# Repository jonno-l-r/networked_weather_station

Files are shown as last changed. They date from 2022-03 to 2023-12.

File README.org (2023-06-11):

#+title: Networked Weather Monitoring Station
#+options: h:4 num:nil toc:t

This is a full stack implementation of a networked weather monitoring station. The repository contains hardware designs, including printed circuit board (PCB) designs for the control and sensor breakout modules, mechanical assembly designs for the custom sensors, embedded sources for the microcontroller, and finally sources for a web API and GUI.

* Overview
#+HEADER: :imagemagick yes :iminoptions -density 400
#+HEADER: :fit yes :noweb yes
#+begin_src latex :file (cond-exp "doc/media/system_diagram0") :results file raw :exports results
  \import{doc/media}{system_diagram.pdf_tex}
#+end_src

#+CAPTION: High level system diagram
#+LABEL: fig:doc/media/system_diagram0
#+RESULTS:
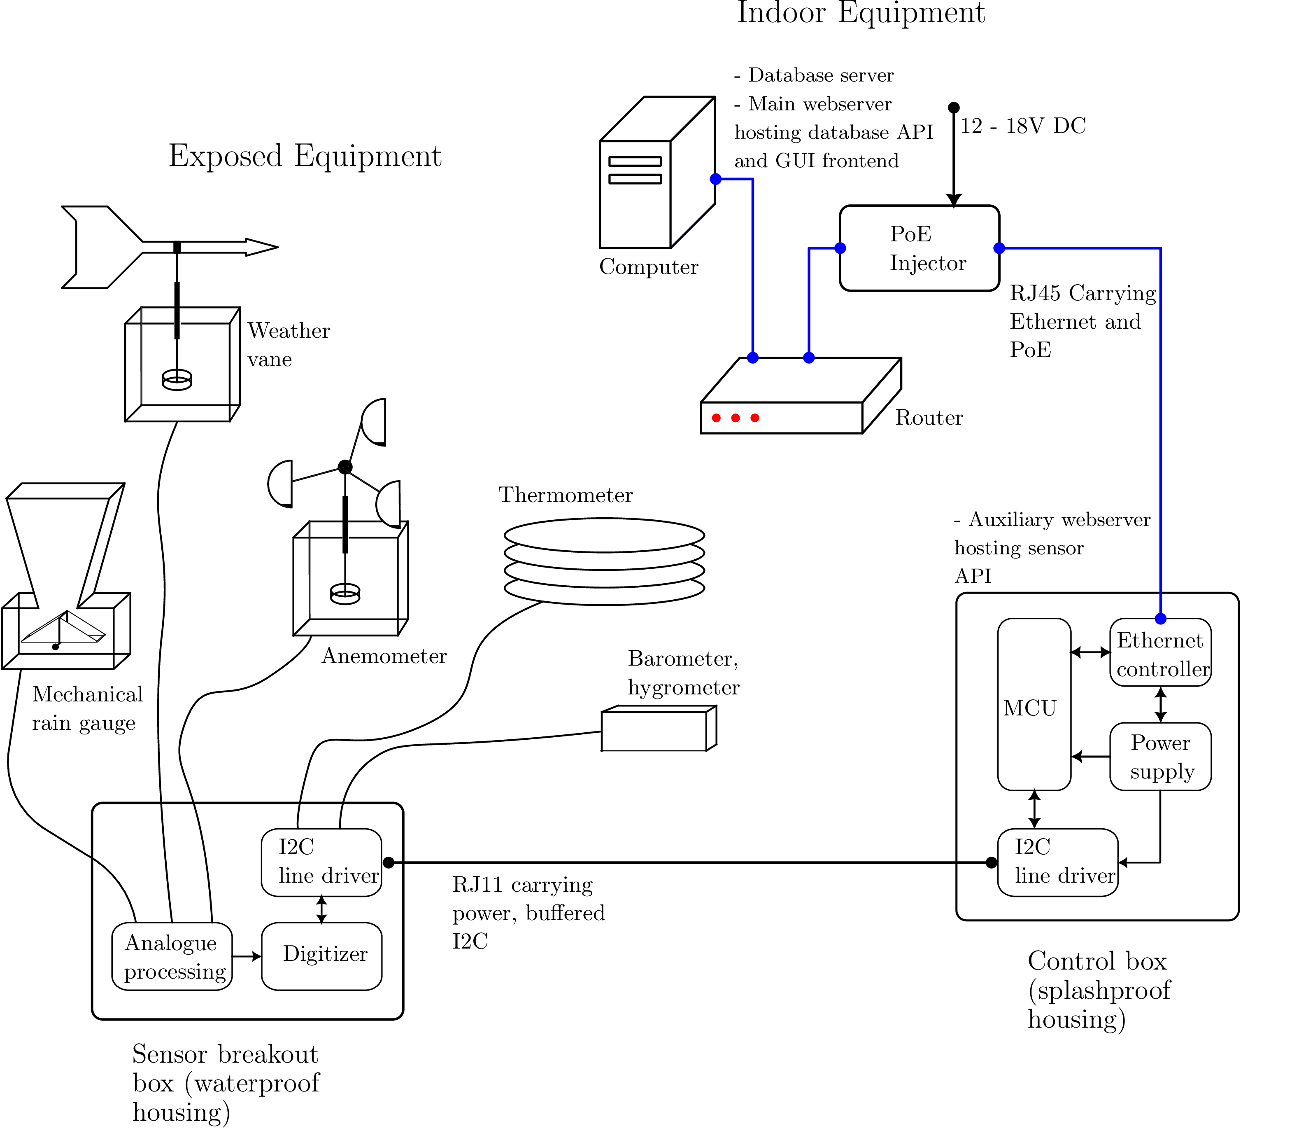
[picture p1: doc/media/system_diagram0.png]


The system is comprised of three main elements; the sensor breakout module and associated sensors, the control module, and the host PC.

All sensors are connected to the breakout module (which is intended to be in close proximity to the sensor cluster). The breakout module is connected to the controller via a single RJ11 link. The controller should be housed in a relatively protected environment. The controller connects to a network switch or router via a power over ethernet injector.

The PC queries the controller over the network at regular intervals, processing the data from the sensors to extrapolate measurements and recording the results into a database. The PC also hosts a web API for the database, along with a web GUI to plot measurement history and current observations.

* Repository Structure
The repository is organised into the following directories;
#+begin_src plantuml :file doc/media/repo.png :exports results
  @startuml
  salt
  {
          {T
          + root
          ++ cad
          +++ electrical
          +++ mechanical
          ++ release
          +++ electrical
          +++ mechanical
          ++ src
          +++ atmega328
          +++ server
          }
  }
  @enduml
#+end_src

#+RESULTS:


Where =cad= holds the electrical and mechanical CAD project files and libraries, =release= holds the exported designs (gerber files, bill of materials and schematics), and =src= holds all microcontroller and server source files and configuration.

The =cad= part of the repository is organised as shown;
#+begin_src plantuml :file doc/media/repo_cad.png :exports results
  @startuml
  salt
  {
          {T
          + root
          ++ cad
          +++ electrical
          ++++ <PCB-module-name>
          +++++ <PCB-module-name>.pro
          +++++ <PCB-module-name>.kicad_pcb
          +++++ <PCB-module-name>.sch
          +++ mechanical
          +++ library
          ++++ custom
          +++++ kicad
          ++++++ footprint
          ++++++ symbol
  }
  }
  @enduml
#+end_src

#+RESULTS:
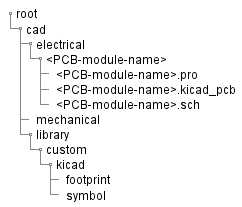
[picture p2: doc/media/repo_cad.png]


The =release= part of the repository is organised as shown below;
#+begin_src plantuml :file doc/media/repo_release.png :exports results
  @startuml
  salt
  {
          {T
          + release
          ++ electrical
          +++ <PCB-module-name>
          ++++ gerber
          ++++ bom.csv
          ++++ schematic.csv
          ++ mechanical
          +++ <mechanical-assembly-name>
          ++++ slicer
          ++++ renders
          ++++ bom.csv
          }
  }
  @enduml
#+end_src

#+RESULTS:
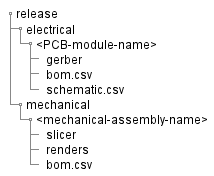
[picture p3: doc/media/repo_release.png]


=release= holds the outputs of the CAD projects in the =cad= directory. The release files are generated on each tagged commit, so the outputs in =release= on any given commit were generated from the projects in =cad= on the last /tagged/ commit.

The =src= part of the repository is orgranised as shown;
#+begin_src plantuml :file doc/media/repo_src.png :exports results
  @startuml
  salt
  {
          {T
          + src
          ++ atmega328
          +++ C
          ++ server
          +++ compose.yml
          +++ mariadb.Dockerfile
          +++ php.Dockerfile
          +++ crontab
          +++ sql
          ++++ db
          ++++ init
          +++ web
          ++++ css
          ++++ js
          ++++ php
          ++++ html
          }
  }
  @enduml
#+end_src

#+RESULTS:
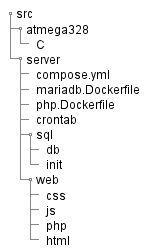
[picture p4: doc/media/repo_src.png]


* Hardware Components
** Sensors
|-------------+----------+----------+-----------|
| Sensor      | Part no. | Accuracy | Interface |
|-------------+----------+----------+-----------|
| Thermometer | MCP9808  | 0.25 °C  | I2C       |
| Hygrometer  | BME280   | 3% RH    | I2C       |
| Barometer   | BME280   | 1.5 hPa  | I2C       |
| Wind vane   | Custom   | TBD      | I2C       |
| Anemometer  | Custom   | TBD      | Analogue  |
| Rain gauge  | Custom   | TBD      | Analogue  |
|-------------+----------+----------+-----------|

** Sensor Breakout Module
The sensor breakout module acts as an interface between the sensors and the control module. It is intended to be in close proximity with the sensors themselves, and in a waterproof enclosure (see [[*Suggested Mounting]]). It interfaces with the controller via RJ11 with 6-pin modular connectors, and interfaces with the sensors via 6x1 pin headers.

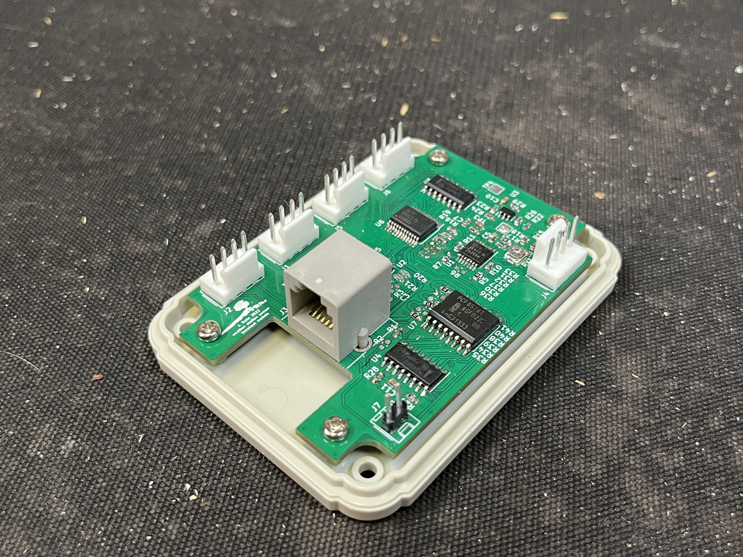
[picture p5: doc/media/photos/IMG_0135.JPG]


** Station Control Module
The controller module contains an Atmega32 microcontroller and a W5500 ethernet controller, which allows the sensors to be controlled over the LAN through an HTTP API. It also contains the system power supplies. Power is carried to the sensors from these supplies via the breakout module. The controller can be powered form a 6mm DC jack or through a primitive, DC form of PoE (power over ethernet). Instructions for the PoE injector are given in [[*PoE Injector Module]].

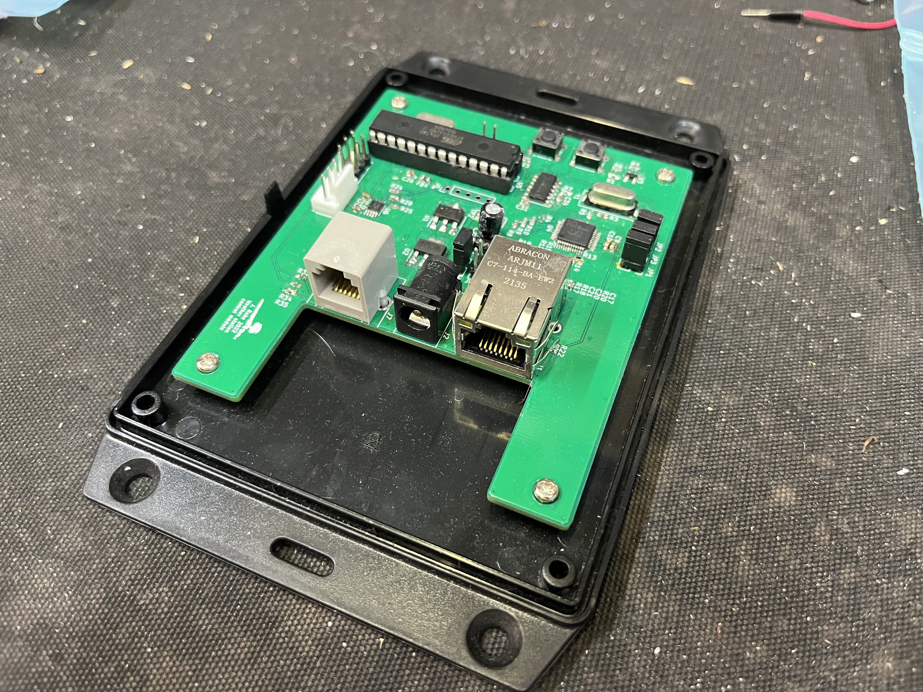
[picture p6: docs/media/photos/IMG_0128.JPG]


** PoE Injector Module
<TODO>

* Hardware Bring Up
** Powerup
For testing, it is convenient to power the control module via the 6mm jack (J2). Connect a jumper to JP4, and ensure no jumper is connected to JP5. Apply 12V to J2. With a voltmeter;
- Verify 5V is present between pin 2 and pin 6 of J3
- Verify 3.3V is present between pin 2 and pin 4 of J5

Next, depress SW2 and verify the following with the voltmeter (while still holding down the switch);
- Pin 1 of U5 is low
- Pin 2 of SW1 is low
Then release SW1 and ensure the voltage at both these points goes high.

If an oscilloscope is available, verify the following with the proble in 10x mode, the timebase set to 0.1us / division and the range set to 100mV / division
- Probe pin 2 of Y1 and verify that the frequency of the signal is 25 MHz
- Probe pin 2 of Y2 and verify that the frequency of the signal is 18 MHz

Connect J7 on the control module to Jx on the breakout module via the RJ11 cable. On the control module, Verify the following with the voltmeter;
- 3.3V is present between pin 3 and pin 4 of J5
- 3.3V is present between pin 1 and pin 4 of J5

And on header J1 of the breakout module, verify;
- 3.3V is present between pins 2 and 4
- 3.3V is present between pins 3 and 4
- 3.3V is present between pins 1 and 4

** Microcontroller programming
*** Configuration
Dynamic DNS is not included in my implementation of the W5500 driver (see =src/atmega328/c/w5500.c=), so a static IP address must be configured. This is set from the main header, =src/atmega328/c/main.h=. Ensure you have reserved this IP address on the router.

The default port for the control module HTTP server is 1000, but this can also be changed from =main.h=. Ensure these network properties have been configured before compiling the source and programming the control module.

*** Compilation
First, all sources under =src/atmega328= must be compiled to a =.hex=. Instructions for compiling with the Microchip Studio IDE (which bundles the AVR GCC toolchain) are given below;

- Open the IDE and create a new 'GCC C Executable' project
- In the wizard, select 'Atmega' from the device family menu and then choose 'ATmega328P' from the device list
- Import the sources and header files from =src/atmega328/c/= into the new project
- Build the project

To program the micrcontroller, an external programming tool will need to be installed (The free version of Microchip Studio doesn't include the programming tool), such as [[https://www.nongnu.org/avrdude/][AVRDude]]. Install AVRDude and ensure the executable is on the system path.

*** Programming over UART
If the microcontroller has a bootloader, it can be programmed over UART. A USB to UART bridge will be needed for this. If an Arduino is available, its USB to UART bridge may be used in place of a standalone bridge. Instructions for this are given be given below;

- On the Arduino, patch the reset pin to one of the GND pins. This will hold the Arduino's microcontroller in reset and prevent it from interfering with the UART link
- Wire the Arduino's RX pin to the TX pin on the control module (pin 2 of J4)
- Wire the Arduino's TX pin to the RX pin on the control module (pin 1 of J4)
- In Microchip Studio, select 'tools', 'external tools', 'Add'
  - Set the entry title to 'UART'
  - Set the command to =<path>\avrdude.exe=
  - Set the arguments to =-C <path>\avrdude.conf -patmega328p -carduino -P\\.\<serial-addr> -b115200 -D -Uflash:w:"$(ProjectDir)Debug\$(TargetName).hex":i= where
    - =path= is the path to the avrdude executable and config file
    - =serial-addr= is the serial address of the Arduino's USB - UART bridge
  - Save the new configuration

The control module can now be programmed over UART.

*** Programming over ISP
If the microcontroller doesn't have a bootloader, it will need to be programmed over the ISP interface. Either an AVR compatible ISP programmer or an Arduino is needed for this. Instructions for programming over ISP with an Arduino are given below;

- Use the Arduino IDE to program the ISP sketch to the Arduino (see file, examples, ArduinoISP)
- Wire the SCLK, MOSI and MISO pins to the ISP header of the control module (header J3)
- In the Microchip Studio IDE, select 'tools', 'external tools', 'Add'
  - Set the entry title to 'Arduino ISP'
  - Set the command to =<path>\avrdude.exe=
  - Set the arguments to =-F -v -p m328p -c arduino -P <serial-addr> -b 19200 -U flash:w:"$(ProjectDir)Debug\$(ItemFileName).hex":i -C"<path>\avrdude.conf"= where
    - =serial-addr= is the serial address of the Arduino
    - =path= is the path to the AVRDude executable and config file
    - Save the new configuration.

The control module can now be programmed over ISP.

** Testing
After the control module has been programmed, connect the various I2C sensor modules to the 4 pin headers of the breakout module, then connect the breakout module to the sensor module via the RJ11 link. Connect the control module to the network and issue a reset by pressing SW2.

Ensure the static IP address set in the control module source does not clash with other devices on the LAN. This address should be reserved in the router configuration.

From a PC on the LAN, ping the control module address to verify the network connection. If the ping is successful, issue an HTTP GET request and verify that the results look reasonable;

#+begin_src python :session :exports both :results output :cached yes :eval never
  import requests
  from pprint import pprint

  data = requests.get("http://<ip-addr>:1000").json()
  pprint(data)
#+end_src

#+RESULTS:
: {'BME280': [{'id': 96},
:             {'div': 1000, 'temperature': 2863},
:             {'div': 2560, 'pressure': 242870758},
:             {'div': 10240, 'humidity': 743179}],
:  'MCP9808': [{'id': 4}, {'div': 160, 'temperature': 620}]}

Then to extract the actual measurements, divide the result by =div=, as shown below;

#+begin_src python :session :exports both :results output cached yes
  def measPrint(measurement, unit):
      return lambda d: (
          print(
              measurement,
              round(d[measurement] / d["div"], 2),
              unit
          )\
          if measurement in d and 'div' in d\
          else None
      )

  print_temp = measPrint("temperature", "deg C")
  print_hum = measPrint("humidity", "%")
  print_pres = measPrint("pressure", "Pa (un-normalised)")

  for sensor in data:
      print("\n%s"%sensor)
      for meas in data[sensor]:
          print_temp(meas)
          print_hum(meas)
          print_pres(meas)
#+end_src

#+RESULTS:
: 
: BME280
: temperature 2.86 deg C
: pressure 94871.39 Pa (un-normalised)
: humidity 72.58 %
: 
: MCP9808
: temperature 3.88 deg C

The results look valid.

* Suggested Mounting
The diagram below illustrates the mounting scheme used for the temperature, humidity and pressure sensors. This mounting configuration ensures:
- The thermometer is exposed to air currents, but not direct radiation
- The hygrometer and barometer are exposed to the open atmosphere, but not precipitation
- The breakout module is fully shielded from the atmosphere

#+HEADER: :imagemagick yes :iminoptions -density 110
#+HEADER: :fit yes :noweb yes
#+begin_src latex :file (cond-exp "doc/media/mounting0") :results file raw :exports results
  \import{doc/media}{mounting.pdf_tex}
#+end_src

#+CAPTION: Sensor, hygrometer and thermometer mounting design
#+LABEL: fig:doc/media/mounting0
#+RESULTS:
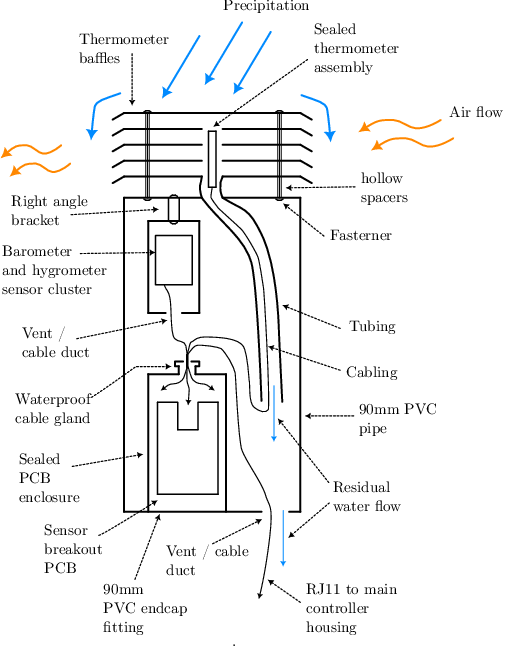
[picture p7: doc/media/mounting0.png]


The MCP9808 PCB was wrapped in soft white rubber tubing, sealed at each end with silicone. This assembly forms the external temperature probe. The BME280 PCB was placed into a small plastic enclosure, which had a hole drilled into the bottom to expose the sensor to the atmosphere. This enclosure was then mounted to the roof of the main enclosure, as shown.

Note the rubber tube running down the main enclosure, which ducts any residual water that penetrates the thermometer baffles down to the hole at the bottom, away from the internal sensors and breakout module.

The breakout module is housed in a fully sealed enclosure, with all cables ducted through a waterproof cable gland.


The following photo was taken during testing. The black enclosure is the control module housing;
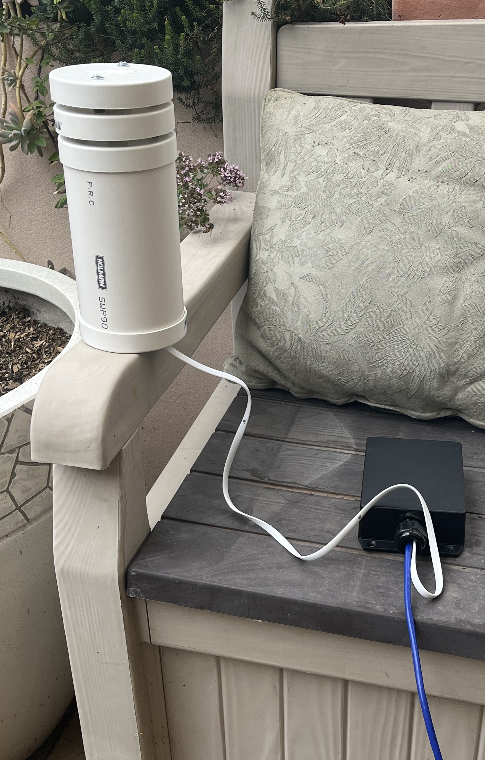
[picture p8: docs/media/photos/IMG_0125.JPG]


* Server Bring up
The following software must be installed on the server
- PHP 8+
- MariaDB 10+
- Apache Web Server

Set up a new user account through the MariaDB monitor, then log out. Log back in as root and run the database initialisation script in =src/server/sql/init/init.sql=.

Copy the contents of =src/server/web= to the web hosting directory. Apache's default is =/var/www/html=. Next, the following environment variables must be set;

#+begin_src sh :eval never
  MARIADB_USER="<db-user-name>"
  MARIADB_PASSWORD="<db-password>"
  MARIADB_DATABASE="weather"
  WEATHER_STATION_ADDRESS="http://<control-module-address>:1000"
  TZ="<your-timezone>"
#+end_src

where =<db-user-name>= and =<db-password>= are the credentials of the database account created earlier.

Database updates will be scheduled on a cron job. =/src/server/web/php/weather_station.php= is the source to be executed. Running this will write a single measurement datapoint from each sensor into the database. Add the following entry to the root cron table;

#+begin_src sh :eval never
  ,*/5 * * * * /usr/local/bin/php <web-server-root>/php/weather_station.php
#+end_src

where =web-server-root= is the path to =src/server/web= on the server. To ensure the cron environment can see the environment variables set earlier, copy them into =/etc/environment=.

The server should now be querying the weather station every five minutes and writing measurements into the MySQL database. After some data has accumulated, start the apache daemon and go to the following address from a web browser (on a different machine, or use =localhost= if testing on the server);

=<server-addr>/php/main.php/sensors/getLatest=

A JSON array of the latest database records should be returned. To view the Web GUI, go to =<server-addr>/html/dashboard.html=.

** Docker
The server components can be run in docker containers, for convenience. Dockerfiles and compose.yml are provided under src/server. The setup is as follows;
- Copy =src/server= to the server
- Edit the =WEATHER_STATION_ADDRESS= property in =compose.yml=
- In the =server= directory, run =docker-compose up -d --build=. This will build two containers; =weather= and =weawther_db=. =weather= containerises the web server, PHP interpreter and cron scheduler, and =weather_db= containerises the MySQL server.
- Launch a bash shell on the =weather= container with =docker exec -it weather_weather bash=
- In the new shell run =printenv > /etc/environment= to copy the container environment variables (set at build time) into the filesystem, then start the cron daemon with =service cron start=
- Exit the shell with =ctrl-d=
- The web server container is forwarded to port 80 on the host. The containerisation will not affect the addressing scheme.

* Web Frontend
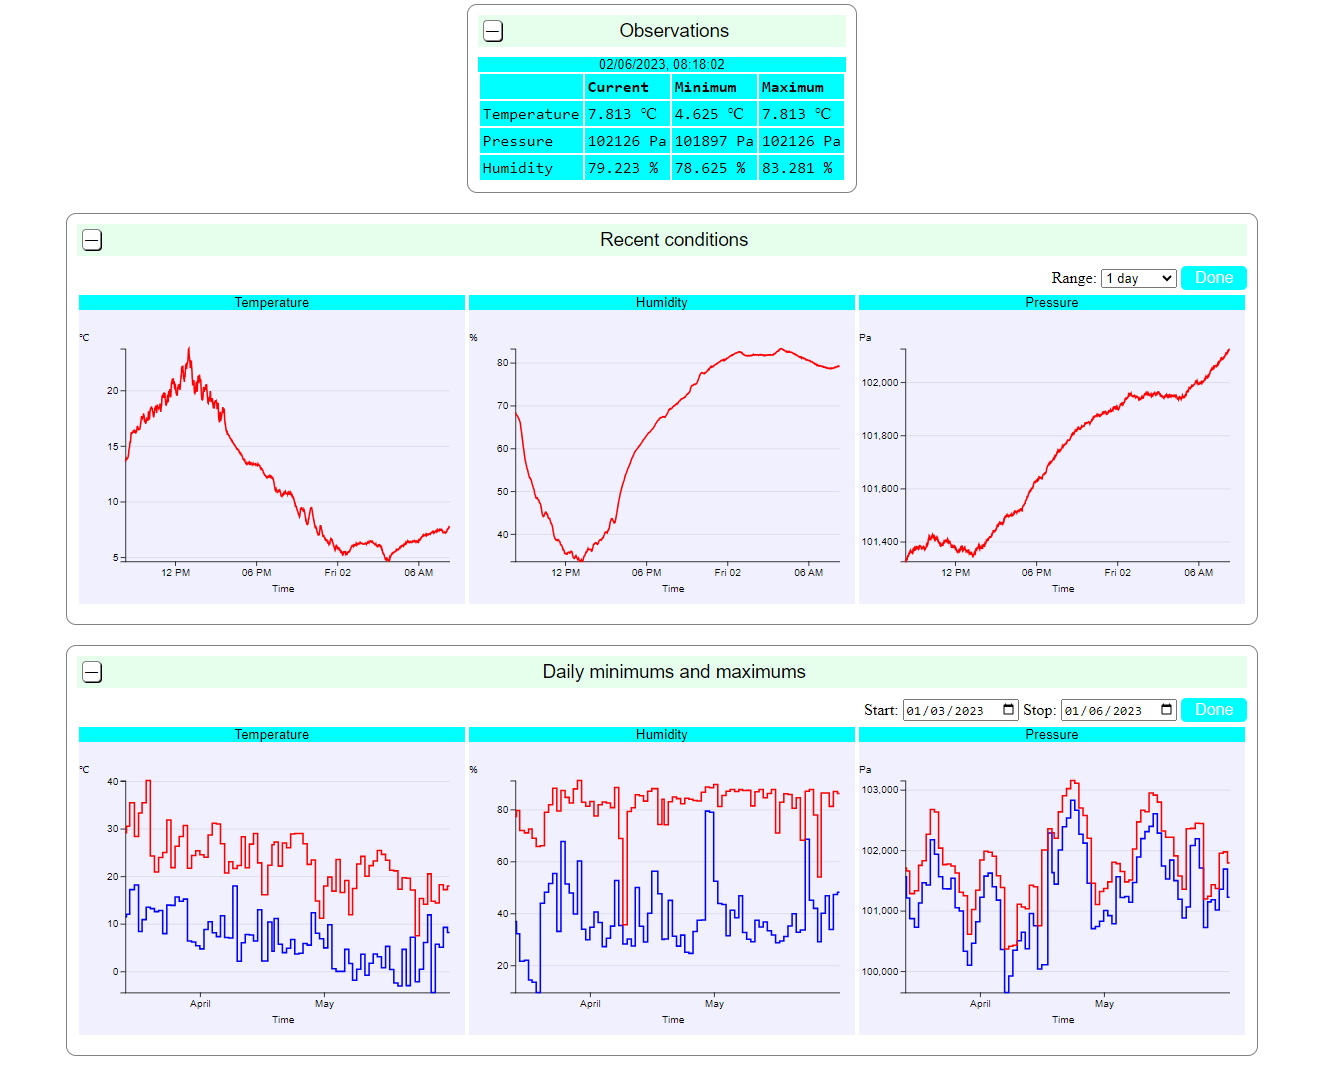
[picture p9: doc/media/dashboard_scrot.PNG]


* Web API
API sources are filed under =src/server/web/php=. The controller is proxied through =main.php=.

Weather records can be accessed programatically through a web API. The addressing scheme is =<server>/main.php/sensors/<endpoint>=. Data is returned as a JSON array of measurement records, where each array element represents a datapoint from a single sensor. The structure is outlined below;

#+begin_example
  [
    {
      "timestamp": <unix-timestamp> [int],
      "sensor_id": <unique sensor identifier> [int],
      "measurement": <measurement name> [string],
      "sensor": <sensor part number> [string],
      "value": <measurement value> [decimal],
      "unit": <measurement unit> [string]
    },

    ...
  ]
#+end_example

API endpoints are summarised below;

** getLatest
=main.php/sensors/getLatest=

Get the most recent database record for all sensors.

Example response:

#+begin_example
[
  {
    "timestamp": "1685657102",
    "sensor_id": "10",
    "measurement": "temperature",
    "sensor": "BME280",
    "value": "6.609",
    "unit": "degree_c"
  },
  {
    "timestamp": "1685657102",
    "sensor_id": "11",
    "measurement": "pressure",
    "sensor": "BME280",
    "value": "95009.032",
    "unit": "Pa"
  },
  
  ...
]
#+end_example

** getBetween
=main.php/sensors/getBetween/?t1=<int>&t2=<int>=

| =t1= | Start timestamp (seconds) [int]              |
| =t2= | Stop timestamp (seconds) [int] (=t2= > =t1=) |

Return all sensor records between =t1= and =t2=.

** getMaxBetween
=main.php/sensors/getMaxBetween/?t1=<int>&t2=<int>&period=<int>=

| =t1=     | Start timestamp (seconds) [int] |
| =t2=     | Stop timestamp (seconds) [int]  |
| =period= | Time span [int] (seconds)       |

Return the maximum records for each sensor in chunks of time =period= between =t1= and =t2=. E.g. if =t1 = <start>=, =t2 = t1 + 60*60*24*7= and =period = 60*60*24=, the maximum records in each interval of 24 hours will be returned across one week (i.e. daily maximums across one week will be returned)

** getMinBetween
=main.php/sensors/getMinBetween/?t1=<int>&t2=<int>&period=<int>=

Like =getMaxBetween=, but returns the /minimum/ records in intervals of =period= across =t2 - t1=.

** getAvgBetween
=main.php/sensors/getAvgBetween/?t1=<int>&t2=<int>&period=<int>=

Returns the /mean/ of all records for each sensor in intervals of =period= across =t2 - t1=.

** getOver
=main.php/sensors/getOver/?t1=<int>&t2=<int>&id=<int>&=thresholds=<decimal>=

| =t1=        | Start timestamp (seconds) [int] |
| =t2=        | Stop timestamp (seconds) [int]  |
| =id=        | Sensor ID [int]                 |
| =threshold= | Record threshold [decimal]      |

Return all records above =threshold= for the sensor =id= over the time span =t2 - t1=

** getUnder
=main.php/sensors/getUnder/?t1=<int>&t2=<int>&id=<int>&=thresholds=<decimal>=

Like =getAbove=, but returns all records /below/ =threshold= for the sensor =id= over the time span =t2 - t1=

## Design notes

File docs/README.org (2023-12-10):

# -*- org-confirm-babel-evaluate: nil -*-
#+FILETAGS: :project:electronics:microcontroller:
#+html_head: <link rel="stylesheet" type="text/css" href="../../shared/css/article.css"/>
#+options: h:4 num:t toc:t
#+author: J. Rabe
#+email: jonno1.l.r@gmail.com

#+begin_src emacs-lisp :results list :wrap tags :exports results
  org-file-tags
#+end_src

#+DATE: [2023-12-03 Sun 15:12]
#+title: Networked Weather Monitoring Station
#+options: h:4 num:nil toc:t

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

* Overview
#+HEADER: :imagemagick yes :iminoptions -density 400
#+HEADER: :fit yes :noweb yes
#+begin_src latex :file (cond-exp "media/system_diagram0") :results file raw :exports results
  \import{media}{system_diagram.pdf_tex}
#+end_src

#+CAPTION: High level system diagram
#+LABEL: fig:media/system_diagram0
#+RESULTS:


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

* Repository Structure
The repository is organised into the following directories;
#+begin_src plantuml :file media/repo.png :exports results
  @startuml
  salt
  {
          {T
          + root
          ++ cad
          +++ electrical
          +++ mechanical
          ++ release
          +++ electrical
          +++ mechanical
          ++ src
          +++ atmega328
          +++ server
          }
  }
  @enduml
#+end_src

#+RESULTS:


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

The =cad= part of the repository is organised as shown;
#+begin_src plantuml :file media/repo_cad.png :exports results
  @startuml
  salt
  {
          {T
          + root
          ++ cad
          +++ electrical
          ++++ <PCB-module-name>
          +++++ <PCB-module-name>.pro
          +++++ <PCB-module-name>.kicad_pcb
          +++++ <PCB-module-name>.sch
          +++ mechanical
          +++ library
          ++++ custom
          +++++ kicad
          ++++++ footprint
          ++++++ symbol
  }
  }
  @enduml
#+end_src

#+RESULTS:


The =release= part of the repository is organised as shown below;
#+begin_src plantuml :file media/repo_release.png :exports results
  @startuml
  salt
  {
          {T
          + release
          ++ electrical
          +++ <PCB-module-name>
          ++++ gerber
          ++++ bom.csv
          ++++ schematic.csv
          ++ mechanical
          +++ <mechanical-assembly-name>
          ++++ slicer
          ++++ renders
          ++++ bom.csv
          }
  }
  @enduml
#+end_src

#+RESULTS:


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

The =src= part of the repository is orgranised as shown;
#+begin_src plantuml :file media/repo_src.png :exports results
  @startuml
  salt
  {
          {T
          + src
          ++ atmega328
          +++ C
          ++ server
          +++ compose.yml
          +++ mariadb.Dockerfile
          +++ php.Dockerfile
          +++ crontab
          +++ sql
          ++++ db
          ++++ init
          +++ web
          ++++ css
          ++++ js
          ++++ php
          ++++ html
          }
  }
  @enduml
#+end_src

#+RESULTS:


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



** PoE Injector Module
<TODO>

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

The control module can now be programmed over UART.

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

The control module can now be programmed over ISP.

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

  data = requests.get("http://<ip-addr>:1000").json()
  pprint(data)
#+end_src

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

Then to extract the actual measurements, divide the result by =div=, as shown below;

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

  print_temp = measPrint("temperature", "deg C")
  print_hum = measPrint("humidity", "%")
  print_pres = measPrint("pressure", "Pa (un-normalised)")

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

The results look valid.

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

#+HEADER: :imagemagick yes :iminoptions -density 110
#+HEADER: :fit yes :noweb yes
#+begin_src latex :file (cond-exp "media/mounting0") :results file raw :exports results
  \import{media}{mounting.pdf_tex}
#+end_src

#+CAPTION: Sensor, hygrometer and thermometer mounting design
#+LABEL: fig:media/mounting0
#+RESULTS:


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

The breakout module is housed in a fully sealed enclosure, with all cables ducted through a waterproof cable gland.


The following photo was taken during testing. The black enclosure is the control module housing;


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

where =<db-user-name>= and =<db-password>= are the credentials of the database account created earlier.

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

#+begin_src sh :eval never
  ,*/5 * * * * /usr/local/bin/php <web-server-root>/php/weather_station.php
#+end_src

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

=<server-addr>/php/main.php/sensors/getLatest=

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

* Web Frontend


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

    ...
  ]
#+end_example

API endpoints are summarised below;

** getLatest
=main.php/sensors/getLatest=

Get the most recent database record for all sensors.

Example response:

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

** getBetween
=main.php/sensors/getBetween/?t1=<int>&t2=<int>=

| =t1= | Start timestamp (seconds) [int]              |
| =t2= | Stop timestamp (seconds) [int] (=t2= > =t1=) |

Return all sensor records between =t1= and =t2=.

** getMaxBetween
=main.php/sensors/getMaxBetween/?t1=<int>&t2=<int>&period=<int>=

| =t1=     | Start timestamp (seconds) [int] |
| =t2=     | Stop timestamp (seconds) [int]  |
| =period= | Time span [int] (seconds)       |

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

** getMinBetween
=main.php/sensors/getMinBetween/?t1=<int>&t2=<int>&period=<int>=

Like =getMaxBetween=, but returns the /minimum/ records in intervals of =period= across =t2 - t1=.

** getAvgBetween
=main.php/sensors/getAvgBetween/?t1=<int>&t2=<int>&period=<int>=

Returns the /mean/ of all records for each sensor in intervals of =period= across =t2 - t1=.

** getOver
=main.php/sensors/getOver/?t1=<int>&t2=<int>&id=<int>&=thresholds=<decimal>=

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

Return all records above =threshold= for the sensor =id= over the time span =t2 - t1=

** getUnder
=main.php/sensors/getUnder/?t1=<int>&t2=<int>&id=<int>&=thresholds=<decimal>=

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

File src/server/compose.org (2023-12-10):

#+title: Weather station server setup

* PHP and Apache
#+name: php-dockerfile
#+begin_src sh :tangle php.Dockerfile
  FROM php:8.2-apache
  RUN apt-get update && apt-get install -y cron vim iputils-ping dos2unix
  RUN docker-php-ext-install mysqli
  ADD ./crontab /etc/cron.d/crontab
  RUN dos2unix /etc/cron.d/crontab
  RUN chmod 0644 /etc/cron.d/crontab
  RUN crontab /etc/cron.d/crontab
  RUN cron

  EXPOSE 80
#+end_src

crontab file
#+name: crontab
#+begin_src sh :tangle crontab
  ,*/2 * * * * /usr/local/bin/php /var/www/html/php/new_record.php
#+end_src

Note:
- Must run =printenv >> /etc/environemnt= to copy environment variables into filesystem for access by cron.
- Remove windows linespaces from crontab!
- Ensure DNS is working properly in containers (=/etc/resolv.d=)

* MariaDB
#+name: mariadb-dockerfile
#+begin_src sh :tangle mariadb.Dockerfile
  FROM mariadb:10.3
#+end_src

DB initialisation script
#+name: db_init
#+begin_src sql :tangle sql/init/init.sql
  USE weather;

  CREATE TABLE sensors (
         id INT NOT NULL AUTO_INCREMENT,
         measurement ENUM('temperature', 'pressure', 'humidity') NOT NULL,
         sensor VARCHAR(10) NOT NULL,
         unit ENUM('degree_c', 'Pa', '%'),

         PRIMARY KEY(id)
  );

  CREATE TABLE canberra_data (
         timestamp INT NOT NULL,
         sensor_id INT NOT NULL,
         value REAL,

         PRIMARY KEY(timestamp, sensor_id),
         CONSTRAINT FOREIGN KEY(sensor_id) REFERENCES sensors(id)
         ON UPDATE CASCADE ON DELETE NO ACTION
  );

  INSERT INTO sensors VALUES (10, 'temperature', 'BME280', 'degree_c');
  INSERT INTO sensors VALUES (11, 'pressure', 'BME280', 'Pa');
  INSERT INTO sensors VALUES (12, 'humidity', 'BME280', '%');
  INSERT INTO sensors VALUES (13, 'temperature', 'MCP9808', 'degree_c');

  GRANT select,insert ON weather_test.* TO 'utest';
  FLUSH PRIVILEGES;
#+end_src

* Compose
#+name: docker-compose
#+begin_src yaml :tangle compose.yml
  networks:
    public:
      external:
        name: frontend
    private:
  services:
    weather:
      build:
        context: ./
        dockerfile: "php.Dockerfile"
      restart: "always"
      ports:
        - "1000:1000"
      volumes:
        - type: bind
          source: ./web
          target: /var/www/html
        - type: bind
          source: ./log
          target: /var/log/apache2
      networks:
        - public
        - private
      environment:
        - MARIADB_USER=${MARIADB_USER:-utest}
        - MARIADB_PASSWORD=${MARIADB_PASSWORD:-utest}
        - MARIADB_DATABASE=weather
        - MARIADB_DATABASE_TABLE_NAME=canberra_data
        - WEATHER_STATION_ADDRESS=http://192.168.1.200:1000
        - TZ=Australia/Canberra
    db:
      build:
        context: ./
        dockerfile: mariadb.Dockerfile
      environment:
        - MARIADB_ROOT_PASSWORD=root
        - MARIADB_USER=${MARIADB_USER:-utest}
        - MARIADB_PASSWORD=${MARIADB_PASSWORD:-utest}
        - MARIADB_DATABASE=weather
        - TZ=Australia/Canberra
      volumes:
        - type: bind
          source: ./sql/db
          target: /var/lib/mysql
        - type: bind
          source: ./sql/init
          target: /docker-entrypoint-initdb.d
      networks:
        - private
#+end_src

* Tangle to remote
#+begin_src yaml :noweb yes :tangle /plink:pi@piserv:/home/pi/docker/weather/compose.yml
  <<docker-compose>>
#+end_src

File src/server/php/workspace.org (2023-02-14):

#+title: Web server backend development notebook
This literate programming document functions as a scratchpad for the database setup and PHP development. All PHP sources are tangled directly from the babel code blocks defined in this document.

* Date and time in PHP
#+begin_src php :dir /plink:pi@piserv#60127:~/src/c/ :results output text
  function makePerson($name, $age){
    $obj->name = $name;
    $obj->age = $age;
    $obj->key = spl_object_hash($obj);

    return $obj;
  }

  $people = array(
      makePerson("Bob", 20),
      makePerson("Paul", 25),
      makePerson("Gwenda", 98)
  );

  echo json_encode($people); 
#+end_src

#+RESULTS:
: [{"name":"Bob","age":20,"key":"00000000147455e2000000007525dfa9"},{"name":"Paul","age":25,"key":"00000000147455e1000000007525dfa9"},{"name":"Gwenda","age":98,"key":"00000000147455e0000000007525dfa9"}]

#+begin_src php :dir /plink:pi@piserv#60127:~/src/c/ :results output text
  $timestamp = time();
  echo "Unix timestamp: ", $timestamp;

  $date = date("Y-m-d H:i:s", $timestamp);
  echo "\nDate and time: ", $date;
#+end_src

#+RESULTS:
: Unix timestamp: 1674776783
: Date and time: 2023-01-27 10:46:23

#+begin_src php :dir /plink:pi@piserv#60127:~/src/c/ :results output text
  function test($args="hello"){
      echo $args;
  }

  test();
#+end_src

#+RESULTS:
: hello

* MySQL database scratch space
Select rows given unit and sensor
#+begin_src sql :engine mysql :dbuser utest :dir /plink:pi@piserv#60127:~/ :results output table :cache yes :exports both
  USE weather_test;
  SELECT MAX(c.timestamp), s.measurement, s.sensor, c.value
         FROM sensors s, canberra_data c
         WHERE
          s.unit='degree_c' AND
          s.sensor='MCP9808' AND
          s.id=c.sensor_id;
#+end_src

#+RESULTS[96af6f7cdc383279257de5d01b1c19f1dd505624]:
| MAX(c.timestamp) | measurement | sensor  |  value |
|------------------+-------------+---------+--------|
|       1675420021 | temperature | MCP9808 | 22.438 |

Get all most recent measurements
#+begin_src sql :engine mysql :dbuser utest :dir /plink:pi@piserv#60127:~/ :results output table :cache no :exports both
  USE weather_test;
  SELECT x.timestamp, x.sensor_id, s.measurement, s.sensor, y.value, s.unit
         FROM sensors s, (
              SELECT sensor_id, MAX(timestamp) as timestamp
              FROM canberra_data
              GROUP BY sensor_id
         ) as x
         join canberra_data y
              on x.sensor_id = y.sensor_id
              AND x.timestamp = y.timestamp
              WHERE s.id = x.sensor_id;
#+end_src

#+RESULTS[069b29575205f596a19c9387c07c4d5a65743794]:
|  timestamp | sensor_id | measurement | sensor  |     value | unit     |
|------------+-----------+-------------+---------+-----------+----------|
| 1675488301 |        10 | temperature | BME280  |     19.89 | degree_c |
| 1675488301 |        11 | pressure    | BME280  | 93453.504 | Pa       |
| 1675488301 |        12 | humidity    | BME280  |    42.197 | %        |
| 1675488301 |        13 | temperature | MCP9808 |    20.438 | degree_c |

Get all measurements between two timestamps
#+begin_src sql :engine mysql :dbuser utest :dir /plink:pi@piserv#60127:~/ :results output table :cache yes :exports both
  USE weather_test;
  SELECT c.timestamp, c.sensor_id, s.measurement, s.sensor, c.value, s.unit
         FROM canberra_data c, sensors s
         WHERE s.id = c.sensor_id
         AND c.timestamp BETWEEN 1675480322 AND 1675480622;
#+end_src

#+RESULTS[79a27193c6a5bca2c9f8e25c8d5b82a31a0b52d5]:
|  timestamp | sensor_id | measurement | sensor  |     value | unit     |
|------------+-----------+-------------+---------+-----------+----------|
| 1675480322 |        10 | temperature | BME280  |     18.94 | degree_c |
| 1675480381 |        10 | temperature | BME280  |     18.94 | degree_c |
| 1675480441 |        10 | temperature | BME280  |     18.95 | degree_c |
| 1675480501 |        10 | temperature | BME280  |     18.96 | degree_c |
| 1675480561 |        10 | temperature | BME280  |     18.96 | degree_c |
| 1675480622 |        10 | temperature | BME280  |     18.98 | degree_c |
| 1675480322 |        11 | pressure    | BME280  | 93410.723 | Pa       |
| 1675480381 |        11 | pressure    | BME280  | 93416.195 | Pa       |
| 1675480441 |        11 | pressure    | BME280  | 93414.215 | Pa       |
| 1675480501 |        11 | pressure    | BME280  | 93408.273 | Pa       |
| 1675480561 |        11 | pressure    | BME280  | 93416.484 | Pa       |
| 1675480622 |        11 | pressure    | BME280  | 93402.363 | Pa       |
| 1675480322 |        12 | humidity    | BME280  |    42.429 | %        |
| 1675480381 |        12 | humidity    | BME280  |    42.417 | %        |
| 1675480441 |        12 | humidity    | BME280  |    42.406 | %        |
| 1675480501 |        12 | humidity    | BME280  |    42.428 | %        |
| 1675480561 |        12 | humidity    | BME280  |    42.529 | %        |
| 1675480622 |        12 | humidity    | BME280  |    42.528 | %        |
| 1675480322 |        13 | temperature | MCP9808 |    19.438 | degree_c |
| 1675480381 |        13 | temperature | MCP9808 |      19.5 | degree_c |
| 1675480441 |        13 | temperature | MCP9808 |      19.5 | degree_c |
| 1675480501 |        13 | temperature | MCP9808 |      19.5 | degree_c |
| 1675480561 |        13 | temperature | MCP9808 |      19.5 | degree_c |
| 1675480622 |        13 | temperature | MCP9808 |    19.563 | degree_c |

Get maximums or minimums
#+begin_src sql :engine mysql :dbuser utest :dir /plink:pi@piserv#60127:~/ :results output table :cache no :exports both
  USE weather_test;
  SELECT y.timestamp, y.sensor_id, x.value
         FROM (
              SELECT timestamp, sensor_id, MAX(value) as value
              FROM canberra_data
              GROUP BY sensor_id
         ) as x
         join canberra_data y
              ON x.sensor_id = y.sensor_id
              AND x.value = y.value;
#+end_src

#+RESULTS[b092b5b29d72bb1eb62f051975aa4ff95516c9d7]:
|  timestamp | sensor_id |     value |
|------------+-----------+-----------|
| 1675076581 |        11 | 93751.926 |
| 1675076701 |        11 | 93751.926 |
| 1675097341 |        12 |     60.61 |
| 1675097461 |        12 |     60.61 |
| 1675232162 |        10 |     24.33 |
| 1675232162 |        13 |    25.188 |
| 1675232221 |        10 |     24.33 |
| 1675232281 |        10 |     24.33 |

Get averages between two timestamps
#+begin_src sql :engine mysql :dbuser utest :dir /plink:pi@piserv#60127:~/ :results output table :cache no :exports both
  USE weather_test;
  -- SELECT x.sensor_id, s.measurement, s.sensor, x.value
  -- FROM (
  --      SELECT sensor_id, AVG(value) as value
  --      FROM canberra_data
  --      WHERE timestamp BETWEEN 1675480322 AND 1675480622
  --      GROUP BY sensor_id
  -- ) as x
  -- join sensors s
  -- on x.sensor_id = s.id;

  SELECT c.sensor_id, s.measurement, s.sensor, AVG(value), s.unit
  FROM canberra_data c, sensors s
  WHERE timestamp BETWEEN 1675480322 AND 1675480622
  AND s.id = c.sensor_id
  GROUP BY sensor_id
#+end_src

#+RESULTS[2d13e165b50bb3a05c6abdcf933662856f0b80f6]:
| sensor_id | measurement | sensor  |         AVG(value) | unit     |
|-----------+-------------+---------+--------------------+----------|
|        10 | temperature | BME280  | 18.955000000000002 | degree_c |
|        11 | pressure    | BME280  |  93411.37550000001 | Pa       |
|        12 | humidity    | BME280  |  42.45616666666667 | %        |
|        13 | temperature | MCP9808 |  19.50016666666667 | degree_c |

Get all values for a particular ID over or under a threshold
#+begin_src sql :engine mysql :dbuser utest :dir /plink:pi@piserv#60127:~/ :results output table :cache no :exports both
  use weather_test;
  SELECT timestamp, sensor_id, value
  FROM canberra_data
  WHERE timestamp BETWEEN 1675400000 AND 1675482781
  AND sensor_id = 12
  AND value < 41.6;
#+end_src

#+RESULTS:
|  timestamp | sensor_id |  value |
|------------+-----------+--------|
| 1675420081 |        12 | 41.597 |
| 1675420141 |        12 | 41.598 |
| 1675420801 |        12 | 41.591 |
| 1675420861 |        12 | 41.579 |
| 1675420981 |        12 | 41.593 |
| 1675421042 |        12 | 41.593 |
| 1675421221 |        12 | 41.594 |
| 1675421401 |        12 | 41.584 |
| 1675421642 |        12 | 41.597 |
| 1675421881 |        12 | 41.598 |
| 1675422001 |        12 | 41.599 |
| 1675422241 |        12 | 41.589 |
| 1675422422 |        12 | 41.591 |
| 1675422781 |        12 | 41.582 |

Get maximums or minimums over a timespan
#+begin_src sql :engine mysql :dbuser utest :dir /plink:pi@piserv#60127:~/ :results output table :cache no :exports both
  USE weather_test;
  SELECT y.timestamp, y.sensor_id, s.measurement, s.sensor, x.value, s.unit
         FROM sensors s, (
              SELECT timestamp, sensor_id, MAX(value) as value
              FROM canberra_data
              WHERE timestamp BETWEEN 1675450000 AND 1675482781
              GROUP BY sensor_id
         ) as x
         join canberra_data y
         on x.value = y.value
         AND x.sensor_id = y.sensor_id
         WHERE s.id = y.sensor_id;
#+end_src

#+RESULTS:
|  timestamp | sensor_id | measurement | sensor  |     value | unit     |
|------------+-----------+-------------+---------+-----------+----------|
| 1675364401 |        10 | temperature | BME280  |     19.26 | degree_c |
| 1675391281 |        10 | temperature | BME280  |     19.26 | degree_c |
| 1675391341 |        10 | temperature | BME280  |     19.26 | degree_c |
| 1675391461 |        10 | temperature | BME280  |     19.26 | degree_c |
| 1675391582 |        10 | temperature | BME280  |     19.26 | degree_c |
| 1675391641 |        10 | temperature | BME280  |     19.26 | degree_c |
| 1675391761 |        10 | temperature | BME280  |     19.26 | degree_c |
| 1675391882 |        10 | temperature | BME280  |     19.26 | degree_c |
| 1675391941 |        10 | temperature | BME280  |     19.26 | degree_c |
| 1675392001 |        10 | temperature | BME280  |     19.26 | degree_c |
| 1675392841 |        10 | temperature | BME280  |     19.26 | degree_c |
| 1675392901 |        10 | temperature | BME280  |     19.26 | degree_c |
| 1675392961 |        10 | temperature | BME280  |     19.26 | degree_c |
| 1675393021 |        10 | temperature | BME280  |     19.26 | degree_c |
| 1675393081 |        10 | temperature | BME280  |     19.26 | degree_c |
| 1675393201 |        10 | temperature | BME280  |     19.26 | degree_c |
| 1675416721 |        10 | temperature | BME280  |     19.26 | degree_c |
| 1675482721 |        10 | temperature | BME280  |     19.26 | degree_c |
| 1675482781 |        10 | temperature | BME280  |     19.26 | degree_c |
| 1675478581 |        11 | pressure    | BME280  | 93445.223 | Pa       |
| 1675458241 |        12 | humidity    | BME280  |    43.516 | %        |
| 1675362721 |        13 | temperature | MCP9808 |    19.875 | degree_c |
| 1675362841 |        13 | temperature | MCP9808 |    19.875 | degree_c |
| 1675362902 |        13 | temperature | MCP9808 |    19.875 | degree_c |
| 1675362961 |        13 | temperature | MCP9808 |    19.875 | degree_c |
| 1675363021 |        13 | temperature | MCP9808 |    19.875 | degree_c |
| 1675363141 |        13 | temperature | MCP9808 |    19.875 | degree_c |
| 1675363321 |        13 | temperature | MCP9808 |    19.875 | degree_c |
| 1675363382 |        13 | temperature | MCP9808 |    19.875 | degree_c |
| 1675394161 |        13 | temperature | MCP9808 |    19.875 | degree_c |
| 1675394281 |        13 | temperature | MCP9808 |    19.875 | degree_c |
| 1675394341 |        13 | temperature | MCP9808 |    19.875 | degree_c |
| 1675394702 |        13 | temperature | MCP9808 |    19.875 | degree_c |
| 1675394821 |        13 | temperature | MCP9808 |    19.875 | degree_c |
| 1675394881 |        13 | temperature | MCP9808 |    19.875 | degree_c |
| 1675394941 |        13 | temperature | MCP9808 |    19.875 | degree_c |
| 1675395002 |        13 | temperature | MCP9808 |    19.875 | degree_c |
| 1675395121 |        13 | temperature | MCP9808 |    19.875 | degree_c |
| 1675395181 |        13 | temperature | MCP9808 |    19.875 | degree_c |
| 1675395241 |        13 | temperature | MCP9808 |    19.875 | degree_c |
| 1675395361 |        13 | temperature | MCP9808 |    19.875 | degree_c |
| 1675395422 |        13 | temperature | MCP9808 |    19.875 | degree_c |
| 1675414381 |        13 | temperature | MCP9808 |    19.875 | degree_c |
| 1675414681 |        13 | temperature | MCP9808 |    19.875 | degree_c |
| 1675414741 |        13 | temperature | MCP9808 |    19.875 | degree_c |
| 1675414801 |        13 | temperature | MCP9808 |    19.875 | degree_c |
| 1675414861 |        13 | temperature | MCP9808 |    19.875 | degree_c |
| 1675414921 |        13 | temperature | MCP9808 |    19.875 | degree_c |
| 1675414982 |        13 | temperature | MCP9808 |    19.875 | degree_c |
| 1675415041 |        13 | temperature | MCP9808 |    19.875 | degree_c |
| 1675415101 |        13 | temperature | MCP9808 |    19.875 | degree_c |
| 1675415161 |        13 | temperature | MCP9808 |    19.875 | degree_c |
| 1675415221 |        13 | temperature | MCP9808 |    19.875 | degree_c |
| 1675415282 |        13 | temperature | MCP9808 |    19.875 | degree_c |
| 1675415461 |        13 | temperature | MCP9808 |    19.875 | degree_c |
| 1675415521 |        13 | temperature | MCP9808 |    19.875 | degree_c |
| 1675482541 |        13 | temperature | MCP9808 |    19.875 | degree_c |
| 1675482721 |        13 | temperature | MCP9808 |    19.875 | degree_c |
| 1675482781 |        13 | temperature | MCP9808 |    19.875 | degree_c |
| 1675482841 |        13 | temperature | MCP9808 |    19.875 | degree_c |
| 1675482901 |        13 | temperature | MCP9808 |    19.875 | degree_c |
| 1675482961 |        13 | temperature | MCP9808 |    19.875 | degree_c |
| 1675483021 |        13 | temperature | MCP9808 |    19.875 | degree_c |
| 1675483081 |        13 | temperature | MCP9808 |    19.875 | degree_c |
| 1675483141 |        13 | temperature | MCP9808 |    19.875 | degree_c |
| 1675483201 |        13 | temperature | MCP9808 |    19.875 | degree_c |

* Database classes
#+name: weather_db
#+begin_src php :dir /plink:pi@piserv#60127:~/src/php/ :results output text :tangle weather_db.php
  <?php

  class WeatherDB {
      private $measurement_name;
      private $measurement_id;
      private $sensor_name;
      private $sensor_stmt;

      protected $mysqli;

      const user = "utest";
      const database = "weather_test";
      const host = "localhost";
      const pw = "";
      const metadata_table = "sensors";
      const data_table = "canberra_data";

      const sensor_query = "SELECT id FROM sensors WHERE measurement=? AND sensor=?";

      public function __construct(){
          $this->mysqli = new mysqli(
              self::host,
              self::user,
              self::pw,
              self::database
          );
          $this->sensor_stmt = $this->mysqli->prepare(self::sensor_query);

          if ($this->sensor_stmt){
              $this->sensor_stmt->bind_param(
                  "ss",
                  $this->measurement_name,
                  $this->sensor_name
              );
          }
      }

      public function getMeasurementID($measurement, $sensor){
          $this->measurement_name = $measurement;
          $this->sensor_name = $sensor;
          if ($this->sensor_stmt){
              $this->sensor_stmt->execute();
              $this->measurement_id = $this->sensor_stmt->get_result()->fetch_assoc()["id"];

              return $this->measurement_id;
          }
          else {
              return NULL;
          }
      }

      public function close(){
          $this->mysqli->close();
          if ($this->sensor_stmt){
              $this->sensor_stmt->close();
          }
      }    
  }

  class WriteWeatherDB extends WeatherDB {
      private $value;
      private $timestamp;
      private $data_stmt;
      private $measurement_id;
      private $query;

      const data_query = "INSERT INTO "
                       .WeatherDB::data_table
                       ." (timestamp, sensor_id, value) VALUES (?,?,?)";

      public function __construct(){
          WeatherDB::__construct();
          $this->data_stmt = $this->mysqli->prepare(self::data_query);

          if ($this->data_stmt){
              $this->data_stmt->bind_param(
                  "iid",
                  $this->timestamp,
                  $this->measurement_id,
                  $this->value
              );
          }
      }

      public function writeMeasurements($data){
          $this->timestamp = time();
          $success = (bool)$this->data_stmt;

          if ($this->data_stmt){
              foreach($data as $ID=>$value){
                  $this->measurement_id = $ID;
                  $this->value = $value;
                  $success &= $this->data_stmt->execute();
              }
          }

          return $success;
      }

      public function close(){
          if ($this->data_stmt){
              $this->data_stmt->close();
          }
          WeatherDB::close();
      }
  }

  class ReadWeatherDB extends WeatherDB {
      const sanitize = array(
          "max"=>"MAX",
          "min"=>"MIN",
          "avg"=>"AVG",
          "over"=>">",
          "under"=>"<"
      );

      public function __construct(){
          WeatherDB::__construct();
      }

      private function _queryTable($query){
          $data;
          $result = $this->mysqli->query($query);

          if ($result){
              $data = $result->fetch_all($mode = MYSQLI_ASSOC);
              $result->free_result();
          }

          return $data;
      }

      public function getLatest(){
          return $this->_queryTable(
              "SELECT x.timestamp, x.sensor_id, s.measurement, s.sensor, y.value, s.unit "
              . "FROM " . WeatherDB::metadata_table . " s, "
              . "(SELECT sensor_id, MAX(timestamp) as timestamp "
              . "FROM " . WeatherDB::data_table . " "
              . "GROUP BY sensor_id) AS x "
              . "JOIN ". WeatherDB::data_table ." y "
              . "ON x.sensor_id = y.sensor_id "
              . "AND x.timestamp = y.timestamp "
              . "WHERE s.id = x.sensor_id"
          );
      }

      public function getBetween($t1, $t2){
          /* Where t1 < t2 */

          return $this->_queryTable(
              "SELECT c.timestamp, c.sensor_id, s.measurement, s.sensor, c.value, s.unit "
              . "FROM " . WeatherDB::data_table . " c, " . WeatherDB::metadata_table . " s "
              . "WHERE s.id = c.sensor_id "
              . "AND c.timestamp BETWEEN "
              . (int)$t1 . " AND " . (int)$t2
          );
      }

      private function _queryMaxMinBetween($t1, $t2, $func){
          /* Where t1 < t2 */

          return $this->_queryTable(
              "SELECT x.timestamp, x.sensor_id, s.measurement, s.sensor, x.value, s.unit "
              . "FROM " . WeatherDB::metadata_table . " s, "
              . "(SELECT timestamp, sensor_id, " . self::sanitize[$func] . "(value) as value "
              . "FROM " . WeatherDB::data_table . " "
              . "WHERE timestamp BETWEEN "
              . (int)$t1 . " AND " . (int)$t2 . " "
              . "GROUP BY sensor_id) AS x "
              . "JOIN " . WeatherDB::data_table . " y "
              . "ON x.value = y.value "
              . "AND x.sensor_id = y.sensor_id "
              . "WHERE s.id = y.sensor_id"
          );
      }    

      private function _getMaxMinBetween($t1, $t2, $func, $period){
          $data = array();
          $min_period = 60*60*12;

          if ($period >= $min_period){
              for ($_t1=$t2-$period; $_t1>$t1; $_t1=$_t1-$period){
                  $data = array_merge(
                      $data,
                      $this->_queryMaxMinBetween(
                          $_t1,
                          $_t1+$period,
                          $func
                      )
                  );
              }
          }
          else {
              $data = $this->_queryMaxMinBetween($t1, $t2, $func);
          }

          return $data;
      }

      public function getMaxBetween($t1, $t2, $period=0){
          return $this->_getMaxMinBetween($t1, $t2, "max", $period);
      }

      public function getMinBetween($t1, $t2, $period=0){
          return $this->_getMaxMinBetween($t1, $t2, "min", $period);
      }

      public function getAverageBetween($t1, $t2){
          /* Where t1 < t2 */

          return $this->_queryTable(
              "SELECT c.sensor_id, s.measurement, s.sensor, AVG(value) as value, s.unit "
              . "FROM " . WeatherDB::data_table . " c, " . WeatherDB::metadata_table . " s "
              . "WHERE timestamp BETWEEN "
              . (int)$t1 . " AND " . (int)$t2 . " "
              . "AND s.id = c.sensor_id "
              . "GROUP BY sensor_id "
          );
      }

      private function _getOverUnder($t1, $t2, $id, $threshold, $operator){
          /* Where t1 < t2 */

          return $this->_queryTable(
              "SELECT timestamp, sensor_id, value "
              . "FROM " . WeatherDB::data_table . " "
              . "WHERE timestamp BETWEEN "
              . (int)$t1 . " AND " . (int)$t2 . " "
              . "AND sensor_id = " . (int)$id . " "
              . "AND value " . self::sanitize[$operator] . (float)$threshold
          );
      }

      public function getOver($t1, $t2, $id, $threshold){
          return $this->_getOverUnder(
              $t1, $t2, $id, $threshold, "over"
          );
      }

      public function getUnder($t1, $t2, $id, $threshold){
          return $this->_getOverUnder(
              $t1, $t2, $id, $threshold, "under"
          );
      }    
  }

  function test(){
      $r = new ReadWeatherDB();
      $latest = $r->getUnder(1675400000, 1675482781, 12, 41.6);
      echo json_encode($latest);
  };

  ?>
#+end_src

#+RESULTS:
: [{"timestamp":"1675420081","sensor_id":"12","value":"41.597"},{"timestamp":"1675420141","sensor_id":"12","value":"41.598"},{"timestamp":"1675420801","sensor_id":"12","value":"41.591"},{"timestamp":"1675420861","sensor_id":"12","value":"41.579"},{"timestamp":"1675420981","sensor_id":"12","value":"41.593"},{"timestamp":"1675421042","sensor_id":"12","value":"41.593"},{"timestamp":"1675421221","sensor_id":"12","value":"41.594"},{"timestamp":"1675421401","sensor_id":"12","value":"41.584"},{"timestamp":"1675421642","sensor_id":"12","value":"41.597"},{"timestamp":"1675421881","sensor_id":"12","value":"41.598"},{"timestamp":"1675422001","sensor_id":"12","value":"41.599"},{"timestamp":"1675422241","sensor_id":"12","value":"41.589"},{"timestamp":"1675422422","sensor_id":"12","value":"41.591"},{"timestamp":"1675422781","sensor_id":"12","value":"41.582"}] ?>

#+begin_src php :dir /plink:pi@piserv#60127:~/src/php/ :results output text
  $x = 22.4;
  echo (float)$x;
#+end_src

#+RESULTS:
: 22.4

* Weather station sensor class
#+name: weather_station
#+begin_src php :dir /plink:pi@piserv#60127:~/src/php/ :results output text :tangle weather_station.php
  <?php

  namespace station;
  require_once 'weather_db.php';
  use WriteWeatherDB;

  class WeatherStation {
      const indices = array(
          "BME280" => array(
              "temperature" => 1,
              "pressure" => 2,
              "humidity" => 3
          ),
          "MCP9808" => array(
              "temperature" => 1
          )
      );
      private $url;

      public function __construct($url){
          $this->url = $url;
      }

      public function getData(){
          $response = file_get_contents($this->url);

          return json_decode($response);
      }

      public function getMeasurements(){
          $data = $this->getData();
          $scaled_data = array();

          foreach (self::indices as $sensor=>$measurement){
              foreach ($measurement as $name=>$index){
                  $scaled_data[] = array(
                      "sensor" => $sensor,
                      "measurement" => $name,
                      "value" => round(
                          $data->$sensor[$index]->$name /
                          $data->$sensor[$index]->div,
                          3
                      )
                  );
              }
          }

          return $scaled_data;
      }
  }

  function main(){
      $db = new WriteWeatherDB("canberra_data");
      $w_station = new WeatherStation("http://192.168.1.200:1000");

      $data = $w_station->getMeasurements();
      $data_to_write = array();
      foreach ($data as $i=>$measurement){
          $data_to_write[
              $db->getMeasurementID(
                  $measurement["measurement"],
                  $measurement["sensor"]
              )
          ] = $measurement["value"];
      }

      $success = $db->writeMeasurements($data_to_write);
  }

  main();

  ?>
#+end_src

#+RESULTS:
#+begin_example
success: 1
array(4) {
  [10]=>
  float(22.07)
  [11]=>
  float(93722.469)
  [12]=>
  float(60.323)
  [13]=>
  float(22.438)
}
#+end_example

* Front controller
#+name: controller
#+begin_src php :dir /plink:pi@piserv#60127:~/src/php/ :results output text :tangle controller.php
  <?php
  namespace controller;
  require_once "weather_db.php";
  use ReadWeatherDB;

  class Controller {
      private $db;
      private $endpoint;
      private $request;

      const api_root = "sensors";

      public function __construct($uri, $request){
          $this->db = new ReadWeatherDB();
          $this->_getEndpoint($uri);
          $this->request = $request;
      }

      private function _getEndpoint($_uri){
          $uri = explode("/", $_uri);
          $key = array_search(self::api_root, $uri);

          if ($key){
              $this->endpoint = $key==(count($uri)-1) ?
                              self::api_root : $uri[$key+1];
          }
          else {
              $this->endpoint = NULL;
          }
      }

      public function processRequest(){
          switch ($this->endpoint){
          case "getLatest":
              header("HTTP/1.1 200 OK");
              echo json_encode($this->db->getLatest());
              break;

          case "getBetween":
              header("HTTP/1.1 200 OK");
              echo json_encode(
                  $this->db->getBetween(
                      (int)$this->request["t1"],
                      (int)$this->request["t2"]                    
                  )
              );
              break;

          case "getMaxBetween":
              header("HTTP/1.1 200 OK");
              echo json_encode(
                  $this->db->getMaxBetween(
                      (int)$this->request["t1"],
                      (int)$this->request["t2"],
                      (int)$this->request["period"]
                  )
              );
              break;

          case "getMinBetween":
              header("HTTP/1.1 200 OK");
              echo json_encode(
                  $this->db->getMinBetween(
                      (int)$this->request["t1"],
                      (int)$this->request["t2"],
                      (int)$this->request["period"]
                  )
              );
              break;

          case "getAvgBetween":
              header("HTTP/1.1 200 OK");
              echo json_encode(
                  $this->db->getAverageBetween(
                      (int)$this->request["t1"],
                      (int)$this->request["t2"]                    
                  )
              );
              break;

          case "getOver":
              header("HTTP/1.1 200 OK");
              echo json_encode(
                  $this->db->getOver(
                      (int)$this->request["t1"],
                      (int)$this->request["t2"],
                      (int)$this->request["id"],
                      (float)$this->request["threshold"]
                  )
              );
              break;

          case "getUnder":
              header("HTTP/1.1 200 OK");
              echo json_encode(
                  $this->db->getUnder(
                      (int)$this->request["t1"],
                      (int)$this->request["t2"],
                      (int)$this->request["id"],
                      (float)$this->request["threshold"]
                  )
              );
              break;            

          default:
              header("HTTP/1.1 404 Not Found");
          }
          $this->db->close();
      }
  }

  function test(){
      $x = new Controller("hello/world", array());
  }

  ?>
#+end_src

#+RESULTS: controller

#+name: main
#+begin_src php :tangle main.php
  <?php

  namespace main;
  require_once "controller.php";
  use controller\Controller;

  $x = new Controller(
     $_SERVER["REQUEST_URI"],
     $_GET
  );
  $x->processRequest();

  ?>
#+end_src

* Tangle to server
#+begin_src php :tangle /plink:pi@piserv#60127:/var/www/html/website/apps/weather/php/weather_station.php :noweb yes
  <<weather_station>>
#+end_src

#+begin_src php :tangle /plink:pi@piserv#60127:/var/www/html/website/apps/weather/php/weather_db.php :noweb yes
  <<weather_db>>
#+end_src

#+begin_src php :tangle /plink:pi@piserv#60127:/var/www/html/website/apps/weather/php/controller.php :noweb yes
  <<controller>>
#+end_src

#+begin_src php :tangle /plink:pi@piserv#60127:/var/www/html/website/apps/weather/php/main.php :noweb yes
  <<main>>
#+end_src

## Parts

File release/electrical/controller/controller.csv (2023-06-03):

Reference | Quantity | Value | Footprint | Datasheet
C10 | 1 | 4.7uF | Capacitor_SMD:C_0603_1608Metric | ~
C17 C9 | 2 | 10nF | Capacitor_SMD:C_0603_1608Metric | ~
C21 C20 | 2 | 6.8nF | Capacitor_SMD:C_0603_1608Metric | ~
C22 | 1 | 33uF | Capacitor_THT:CP_Radial_D4.0mm_P2.00mm | ~
C23 | 1 | 22nF | Capacitor_SMD:C_0603_1608Metric | ~
C32 C33 | 2 | DNF | Capacitor_SMD:C_0603_1608Metric | ~
C4 C3 C27 C28 | 4 | 18pF | Capacitor_SMD:C_0603_1608Metric | ~
C7 C18 C5 C1 C2 C6 C24 C35 | 8 | 10uF | Capacitor_SMD:C_0603_1608Metric | ~
C8 C11 C12 C13 C14 C15 C16 C19 C25 C26 C36 C34 C31 C30 C29 | 15 | 100nF | Capacitor_SMD:C_0603_1608Metric | ~
D1 | 1 | D | Diode_THT:D_DO-41_SOD81_P7.62mm_Horizontal | ~
FB1 FB2 FB3 FB4 | 4 | BLM21 | Inductor_SMD:L_0805_2012Metric | ~
J1 | 1 | ARJM11C7-114-BA-EW2 | custom:ARJM11C7-114-BA-EW2 | https://abracon.com/Magnetics/ARJM11.pdf
J2 | 1 | Barrel_Jack_Switch | Connector_BarrelJack:BarrelJack_Horizontal | ~
J3 | 1 | Conn_02x03_Odd_Even | Connector_PinHeader_2.54mm:PinHeader_2x03_P2.54mm_Vertical | ~
J4 | 1 | Conn_01x02 | Connector_PinSocket_2.54mm:PinSocket_1x02_P2.54mm_Vertical | ~
J5 | 1 | Conn_01x04 | Connector_Molex:Molex_KK-254_AE-6410-04A_1x04_P2.54mm_Vertical | ~
J6 | 1 | Conn_01x05 | Connector_PinHeader_2.54mm:PinHeader_1x05_P2.54mm_Vertical | ~
J7 | 1 | 6P6C | custom:E5566-Q0LK22-L | ~
JP5 JP4 JP2 JP1 JP3 | 5 | Jumper | Connector_PinSocket_2.54mm:PinSocket_1x02_P2.54mm_Vertical | ~
R10 R9 R8 R23 R28 R25 R24 | 7 | 10k | Resistor_SMD:R_0603_1608Metric | ~
R11 R14 R12 R15 R5 R7 R1 R35 | 8 | 0 | Resistor_SMD:R_0603_1608Metric | ~
R13 | 1 | 12k4 | Resistor_SMD:R_0603_1608Metric | ~
R19 | 1 | 10 | Resistor_SMD:R_0603_1608Metric | ~
R2 | 1 | 100k | Resistor_SMD:R_0603_1608Metric | ~
R20 R18 R17 R16 | 4 | 49.9 | Resistor_SMD:R_0603_1608Metric | ~
R22 R21 | 2 | 330 | Resistor_SMD:R_0603_1608Metric | ~
R26 R27 | 2 | 75 | Resistor_SMD:R_0603_1608Metric | ~
R3 | 1 | 1M | Resistor_SMD:R_0603_1608Metric | ~
R30 R31 | 2 | 2.2k | Resistor_SMD:R_0603_1608Metric | ~
R4 R33 R34 R29 R32 | 5 | DNF | Resistor_SMD:R_0603_1608Metric | ~
R6 | 1 | 4.7k | Resistor_SMD:R_0603_1608Metric | ~
SW1 SW2 | 2 | SW_Push | Button_Switch_THT:SW_PUSH_6mm | ~
TP2 TP1 | 2 | TestPoint | TestPoint:TestPoint_Pad_2.5x2.5mm | ~
U1 | 1 | NCP1117-5.0_SOT223 | Package_TO_SOT_SMD:SOT-223-3_TabPin2 | http://www.onsemi.com/pub_link/Collateral/NCP1117-D.PDF
U2 | 1 | NCP1117-3.3_SOT223 | Package_TO_SOT_SMD:SOT-223-3_TabPin2 | http://www.onsemi.com/pub_link/Collateral/NCP1117-D.PDF
U3 | 1 | CAT811STBI-GT3 | Package_TO_SOT_SMD:SOT-143 | http://www.onsemi.com/pub/Collateral/CAT811-D.PDF
U4 | 1 | W5500 | Package_QFP:LQFP-48_7x7mm_P0.5mm | https://cdn.sparkfun.com/datasheets/Dev/Arduino/Shields/W5500_datasheet_v1.0.2_1.pdf
U5 | 1 | ATmega328-PU | Package_DIP:DIP-28_W7.62mm | http://ww1.microchip.com/downloads/en/DeviceDoc/ATmega328_P%20AVR%20MCU%20with%20picoPower%20Technology%20Data%20Sheet%2040001984A.pdf
U6 | 1 | PCA9517A | Package_SO:TSSOP-8_3x3mm_P0.65mm
U7 | 1 | TXB0104D | Package_SO:SOIC-14_3.9x8.7mm_P1.27mm | http://www.ti.com/lit/ds/symlink/txb0104.pdf
Y1 | 1 | 25MHz | Crystal:Crystal_SMD_HC49-SD | ~
Y2 | 1 | 18MHz | Crystal:Crystal_SMD_HC49-SD | ~

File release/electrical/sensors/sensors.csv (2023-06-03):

Reference | Quantity | Value | Footprint | Datasheet
C1 | 1 | 10uF | Capacitor_SMD:C_0603_1608Metric | ~
C10 C15 C12 C14 C13 C2 C7 C6 C11 | 9 | 100nF | Capacitor_SMD:C_0603_1608Metric | ~
C4 C3 | 2 | DNF | Capacitor_SMD:C_0603_1608Metric | ~
C5 | 1 | 4.7uF | Capacitor_SMD:C_0603_1608Metric | ~
C8 | 1 | 10nF | Capacitor_SMD:C_0603_1608Metric | ~
C9 | 1 | 1uF | Capacitor_SMD:C_0603_1608Metric | ~
J3 | 1 | MTJ-660x1 | custom:E5566-Q0LK22-L | ~
J4 J2 J6 J1 J5 | 5 | Conn_01x04 | Connector_Molex:Molex_KK-254_AE-6410-04A_1x04_P2.54mm_Vertical | ~
J7 | 1 | Conn_01x02 | Connector_Molex:Molex_KK-254_AE-6410-02A_1x02_P2.54mm_Vertical | ~
R10 R11 | 2 | 1k | Resistor_SMD:R_0603_1608Metric | ~
R12 R13 | 2 | 75 | Resistor_SMD:R_0603_1608Metric | ~
R15 R14 | 2 | 33k | Resistor_SMD:R_0603_1608Metric | ~
R17 R16 | 2 | 39k | Resistor_SMD:R_0603_1608Metric | ~
R18 R5 R7 R37 R33 R31 R35 R39 R41 R1 | 10 | 0 | Resistor_SMD:R_0603_1608Metric | ~
R19 | 1 | 1.6k | Resistor_SMD:R_0603_1608Metric | ~
R23 R24 R28 | 3 | 100k | Resistor_SMD:R_0603_1608Metric | ~
R26 | 1 | 775k | Resistor_SMD:R_0603_1608Metric | ~
R29 R27 R25 R21 R20 | 5 | 10k | Resistor_SMD:R_0603_1608Metric | ~
R6 R30 R32 R36 R22 R2 R9 R4 R40 R38 R34 | 11 | DNF | Resistor_SMD:R_0603_1608Metric | ~
R8 R3 | 2 | 2.2k | Resistor_SMD:R_0603_1608Metric | ~
RV1 | 1 | 10k | Potentiometer_SMD:Potentiometer_Bourns_TC33X_Vertical | ~
TP4 TP1 TP2 TP3 | 4 | RCU-0C | TestPoint:TestPoint_Pad_2.0x2.0mm | ~
U1 | 1 | LMV324 | Package_SO:TSSOP-14_4.4x5mm_P0.65mm | http://www.ti.com/lit/ds/symlink/lmv324.pdf
U2 | 1 | PCA9517A | Package_SO:TSSOP-8_3x3mm_P0.65mm
U3 | 1 | LMV331 | Package_SO:TSOP-5_1.65x3.05mm_P0.95mm | http://www.ti.com/lit/ds/symlink/lmv331.pdf
U5 U4 | 2 | MC14040B | Package_SO:SOIC-16_3.9x9.9mm_P1.27mm | http://www.intersil.com/content/dam/Intersil/documents/cd40/cd4020bms-24bms-40bms.pdf
U6 | 1 | TCA9555DBR | Package_SO:SSOP-24_5.3x8.2mm_P0.65mm | http://www.ti.com/lit/ds/symlink/tca9555.pdf
U7 | 1 | PCF8574 | Package_SO:SOIC-16W_7.5x10.3mm_P1.27mm | http://www.nxp.com/documents/data_sheet/PCF8574_PCF8574A.pdf

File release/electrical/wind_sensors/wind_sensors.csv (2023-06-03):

Reference | Quantity | Value | Footprint | Datasheet
C3 C6 | 2 | 10uF | Capacitor_SMD:C_0603_1608Metric | ~
C4 C1 C2 | 3 | 100nF | Capacitor_SMD:C_0603_1608Metric | ~
C5 C7 | 2 | DNF | Capacitor_SMD:C_0603_1608Metric | ~
J1 J2 | 2 | Conn_01x04 | Connector_Molex:Molex_KK-254_AE-6410-04A_1x04_P2.54mm_Vertical | ~
J3 | 1 | Conn_01x03 | Connector_Molex:Molex_KK-254_AE-6410-03A_1x03_P2.54mm_Vertical | ~
U2 | 1 | HMC1501 | Package_SO:SOIC-8_3.9x4.9mm_P1.27mm
U3 | 1 | AS5601 | Package_SO:SOIC-8_3.9x4.9mm_P1.27mm

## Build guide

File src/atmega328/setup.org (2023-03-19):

#+title: AVR toolchain setup

* Programming
Microchip studio can be configured to use an external programming tool (such as AVRdude) through the 'external tools' dialogue (accessed from the tools menu).

** UART
For programming over UART with AVRdude use the following command;

=avrdude.exe -C "avrdude.conf" -patmega328p -carduino -P\\.\COM<port-number> -b115200 -D -Uflash:w:"$(ProjectDir)Debug\$(TargetName).hex":i=

- Note that =avrdude.conf= is available on the path ="C:\Program Files (x86)\Arduino\hardware\tools\avr\etc\= if the Arduino IDE is installed
- <port-number> is the serial port number

To check which fuses are set using AVRdude, run the following command;

=./avrdude.exe -c avrisp -p m328p -P com8 -b 19200 -U lfuse:r:-:i -v -C "avrdude.conf"=

AVRdude can also be used to view memory usage;

=./avr-size -C --mcu=atmega328 '<project>.elf'=

In Microchip studio, the =.elf= is stored under =<project>/<project>/Debug/<project>.elf=

** ISP
If programming with an ISP programmer (or an Arduino configured as an ISP programmer) through AVRdude, use the following command;

=avrdude.exe -F -v -p m328p -c arduino -P COM<port-number> -b 19200 -U flash:w:"$(ProjectDir)Debug\$(ItemFileName).hex":i -C "avrdude.conf"=

- [[https://www.instructables.com/Integrate-ArduinoISP-and-Atmel-Studio/][This article]] explains how flags can be set with avrdude:
- Arduino provides a sketch which turns the board into an ISP: [[https://learn.adafruit.com/arduino-tips-tricks-and-techniques/arduinoisp#bonus-using-with-avrdude][Link to sketch]]

* Bootloader burning
- Burning bootloader .hex with AVRDUDE: [[https://learn.sparkfun.com/tutorials/installing-an-arduino-bootloader/all][sparkfun article]]
- [[https://www.engbedded.com/fusecalc/][AVR fuse calculator]]
- [[https://github.com/Optiboot/optiboot][Optiboot repo]]
  - Optiboot is an Arduino compatible bootloader for AVR microcontrollers
  - Make command: =make atmega328 AVR_FREQ=18000000L BAUD_RATE=112500=
  - Need packages =gcc-avr= and =avr-libc= to compile optiboot

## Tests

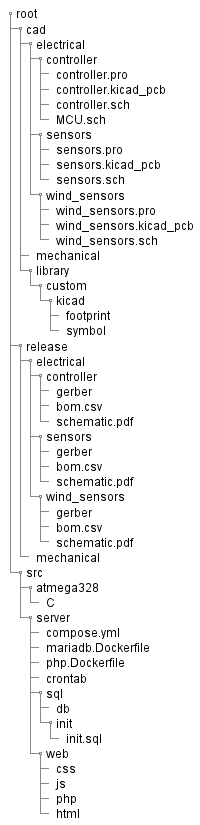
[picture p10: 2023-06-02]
docs/media/test.png

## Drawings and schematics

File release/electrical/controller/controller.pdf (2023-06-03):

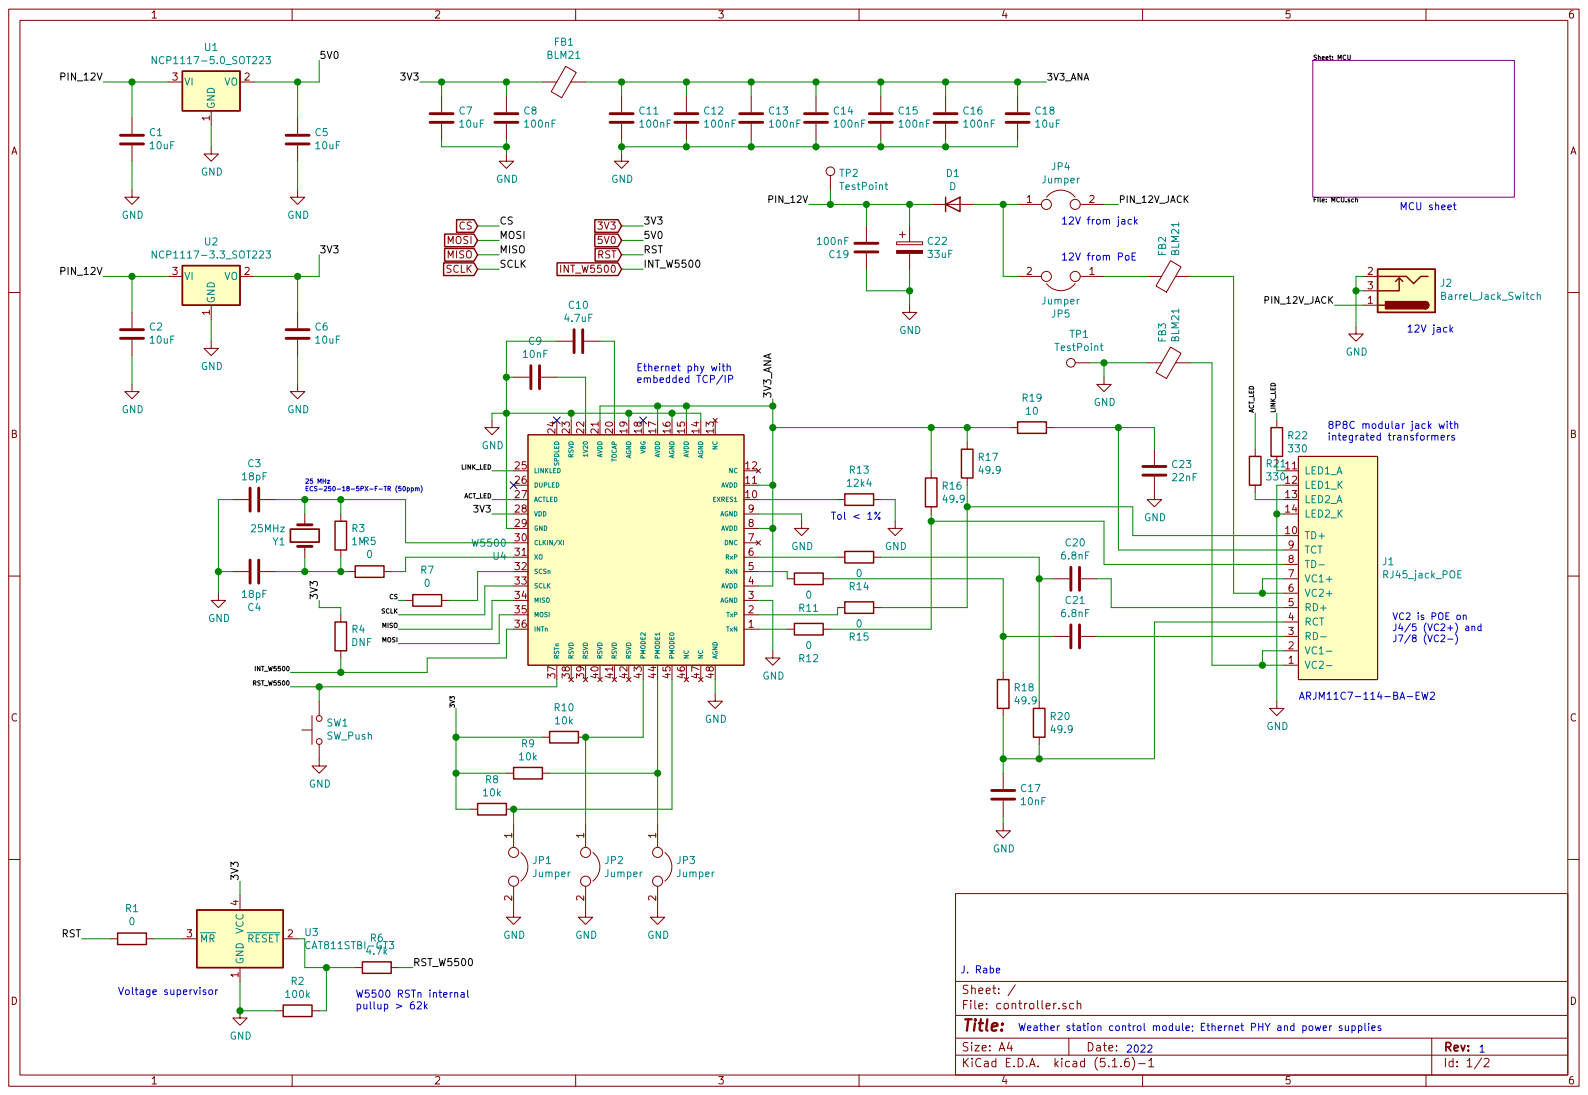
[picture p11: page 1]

File: MCU.sch
integrated transformers MCU sheet

J. Rabe
Id: 1/2 Title: File: controller.sch Sheet: /

Weather station control module; Ethernet PHY and power supplies

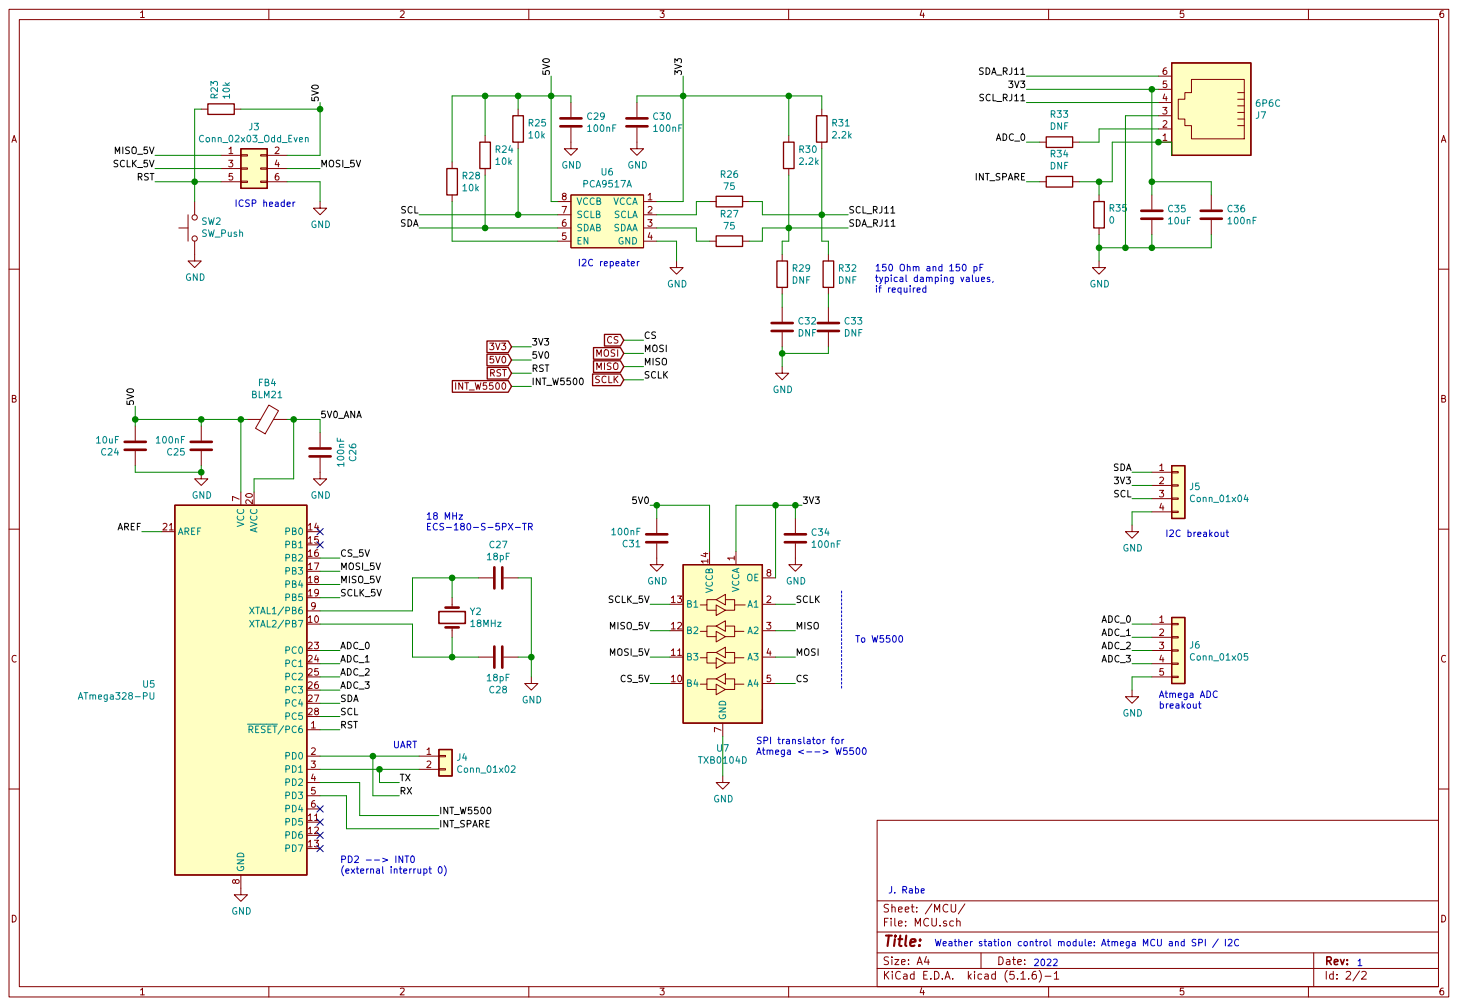
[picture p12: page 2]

ICSP header
(external interrupt 0) 18 MHz ECS-180-S-5PX-TR
SCL CS_5V MOSI_5V MISO_5V

SPI translator for Atmega <--> W5500

J. Rabe
Id: 2/2 Title: File: MCU.sch Sheet: /MCU/

2022 Weather station control module: Atmega MCU and SPI / I2C

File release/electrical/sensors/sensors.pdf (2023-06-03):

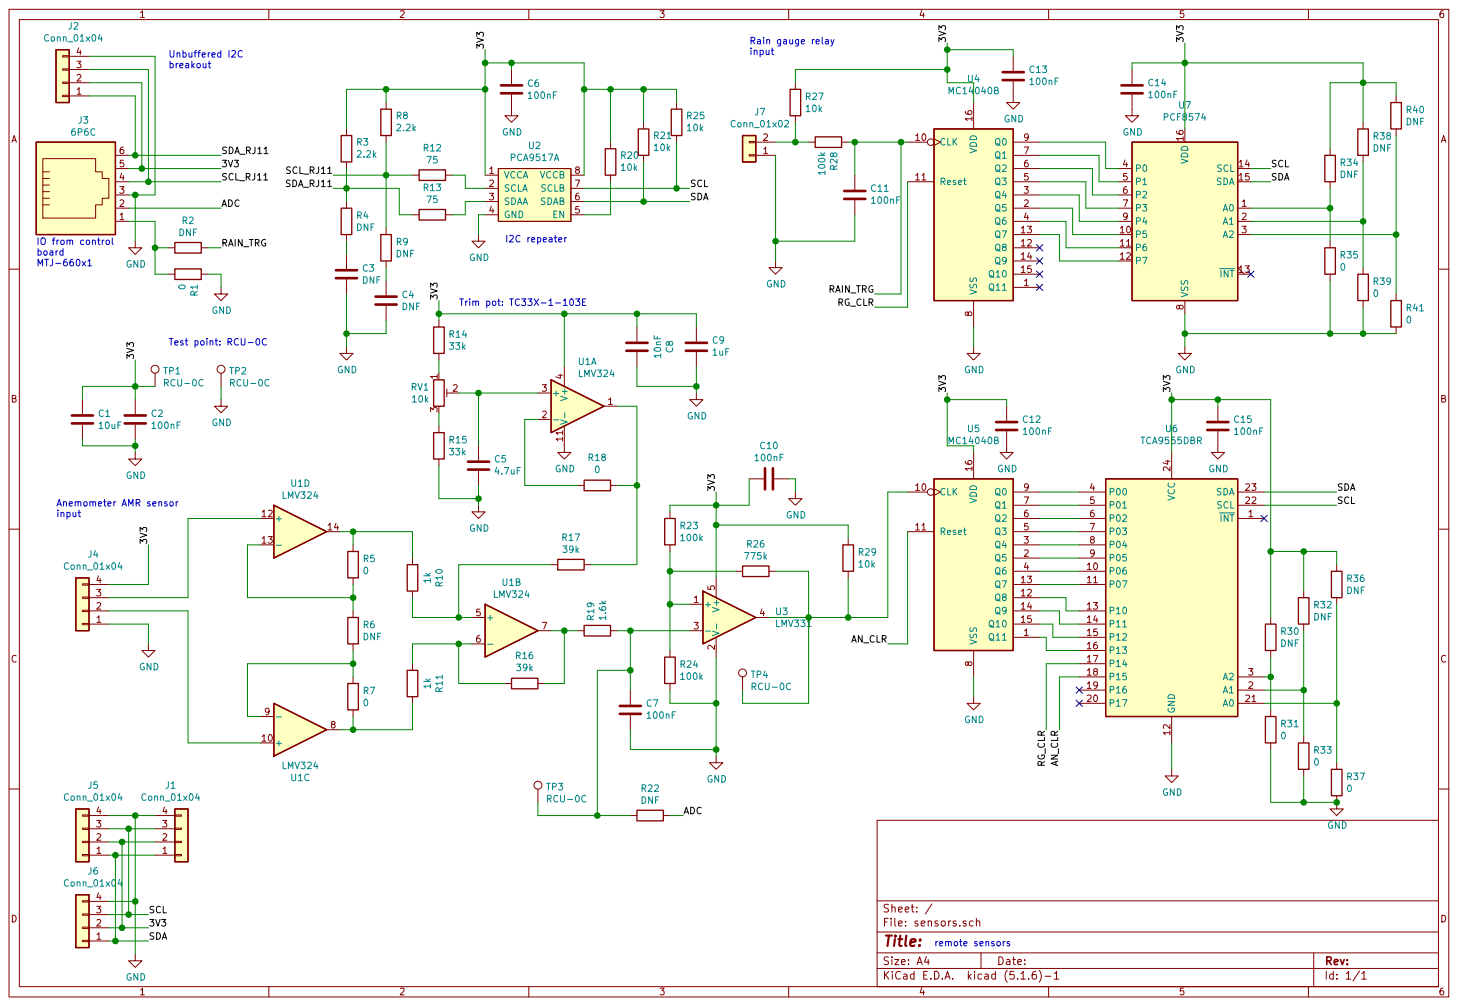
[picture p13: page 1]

SCL_RJ11 SDA_RJ11 Unbuffered I2C breakout Test point: RCU-0C

Id: 1/1 Title: File: sensors.sch Sheet: /

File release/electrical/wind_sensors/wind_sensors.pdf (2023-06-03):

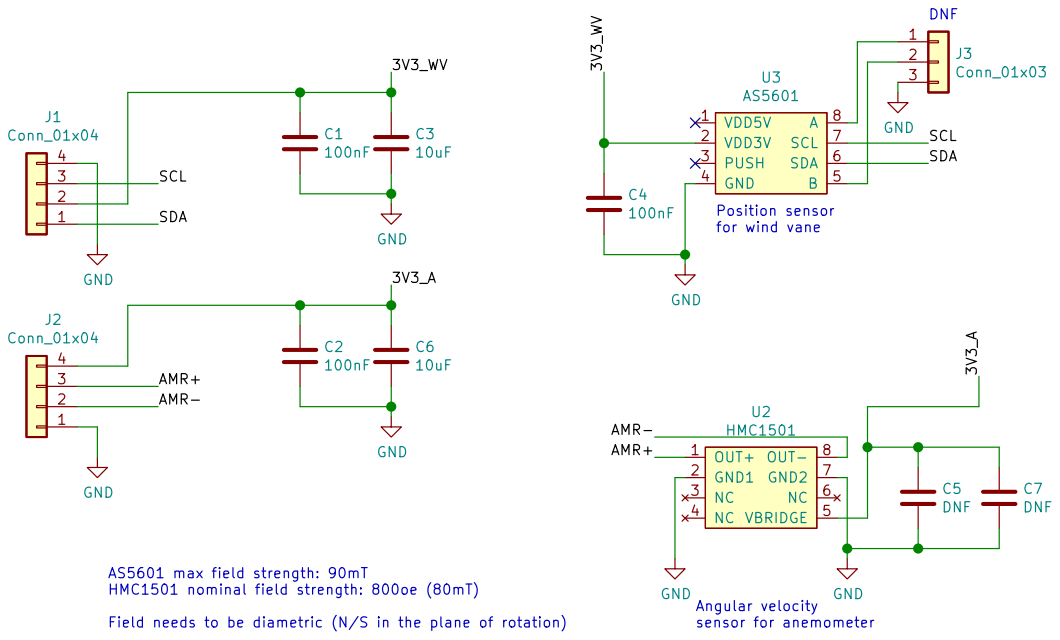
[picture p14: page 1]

Angular velocity sensor for anemometer

Anemometer: DNF J1 and U3 Wind vane: DNF J2 and U2

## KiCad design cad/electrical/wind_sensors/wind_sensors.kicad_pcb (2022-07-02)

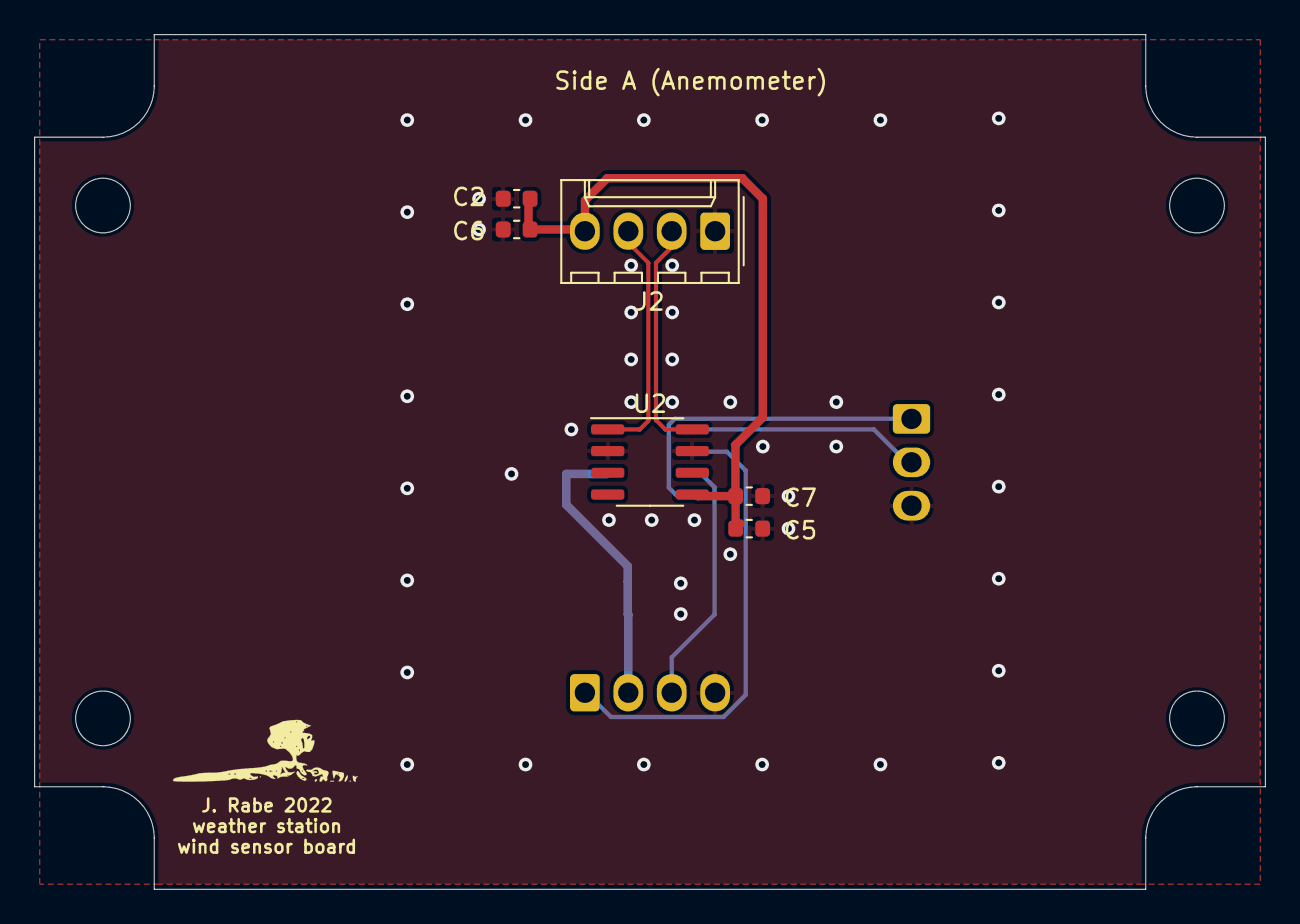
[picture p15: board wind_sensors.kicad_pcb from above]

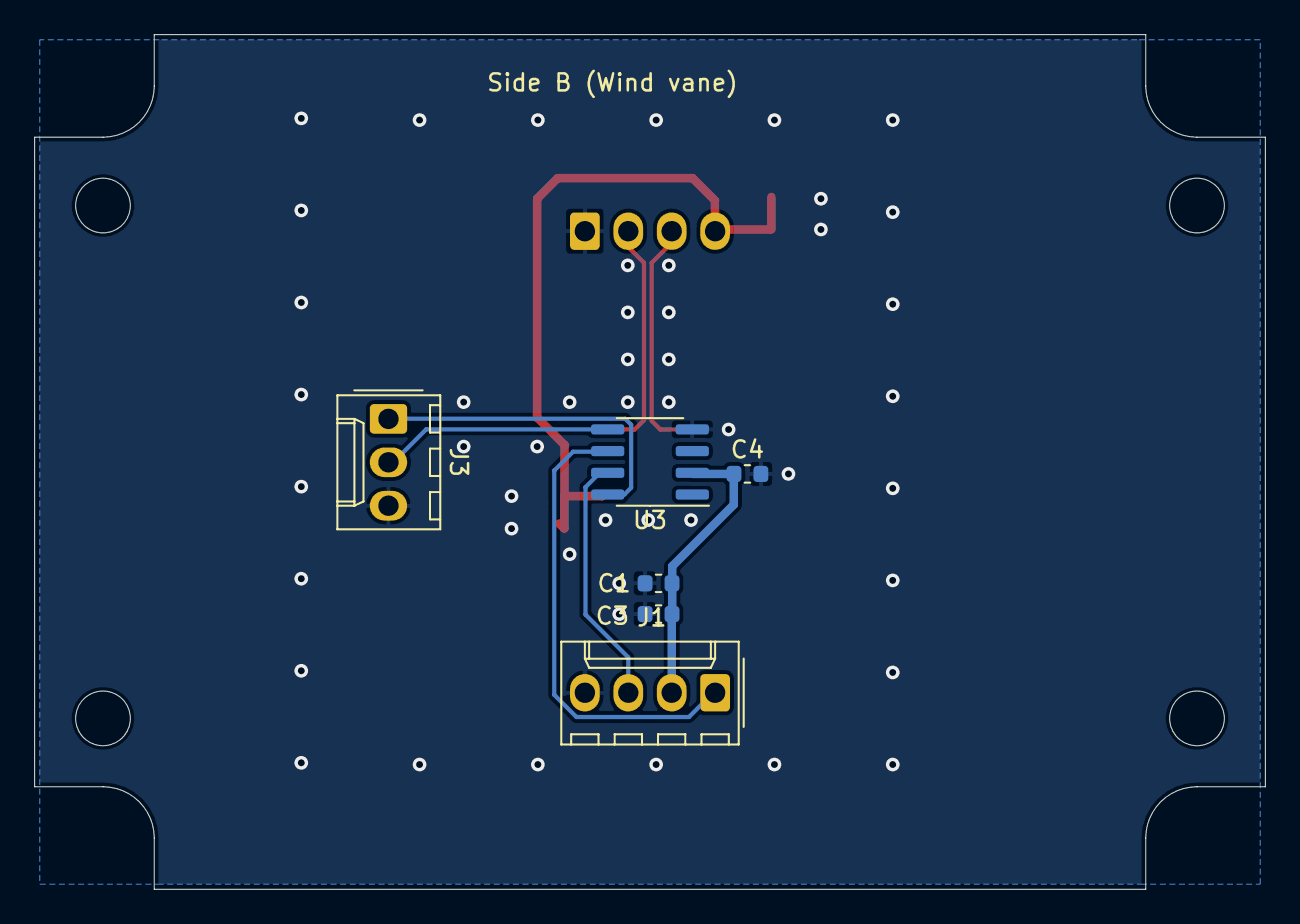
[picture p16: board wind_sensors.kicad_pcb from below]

Board: 2 copper layers, 72.0 x 50.0 mm, 12 parts (6 on the bottom side), 9 nets.

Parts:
C1, C2, C4: 100nF; C_0603_1608Metric
C3, C6: 10uF; C_0603_1608Metric
C5, C7: DNF; C_0603_1608Metric
J1, J2: Conn_01x04; Molex_KK-254_AE-6410-04A_1x04_P2.54mm_Vertical
J3: Conn_01x03; Molex_KK-254_AE-6410-03A_1x03_P2.54mm_Vertical
U2: HMC1501; SOIC-8_3.9x4.9mm_P1.27mm
U3: AS5601; SOIC-8_3.9x4.9mm_P1.27mm

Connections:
/3V3_A: C2.1, C5.1, C6.1, C7.1, J2.4, U2.5
/3V3_WV: C1.1, C3.1, C4.1, J1.2, U3.2
/AMR+: J2.3, U2.1
/AMR-: J2.2, U2.8
/SCL: J1.3, U3.7
/SDA: J1.1, U3.6
GND: C1.2, C2.2, C3.2, C4.2, C5.2, C6.2, C7.2, J1.4, J2.1, J3.3, U2.2, U2.7, U3.4
unnamed: J3.1, U3.8
unnamed: J3.2, U3.5

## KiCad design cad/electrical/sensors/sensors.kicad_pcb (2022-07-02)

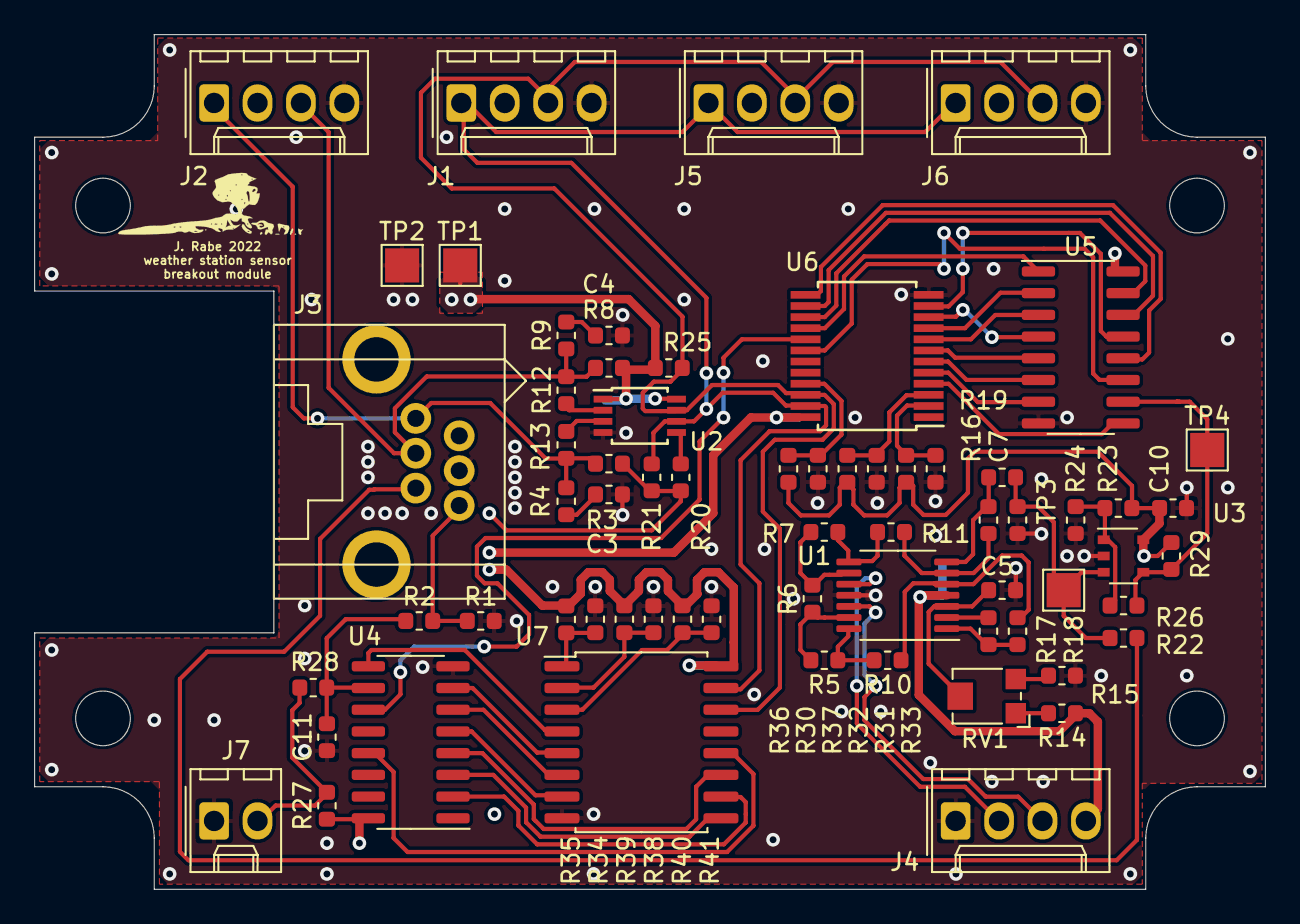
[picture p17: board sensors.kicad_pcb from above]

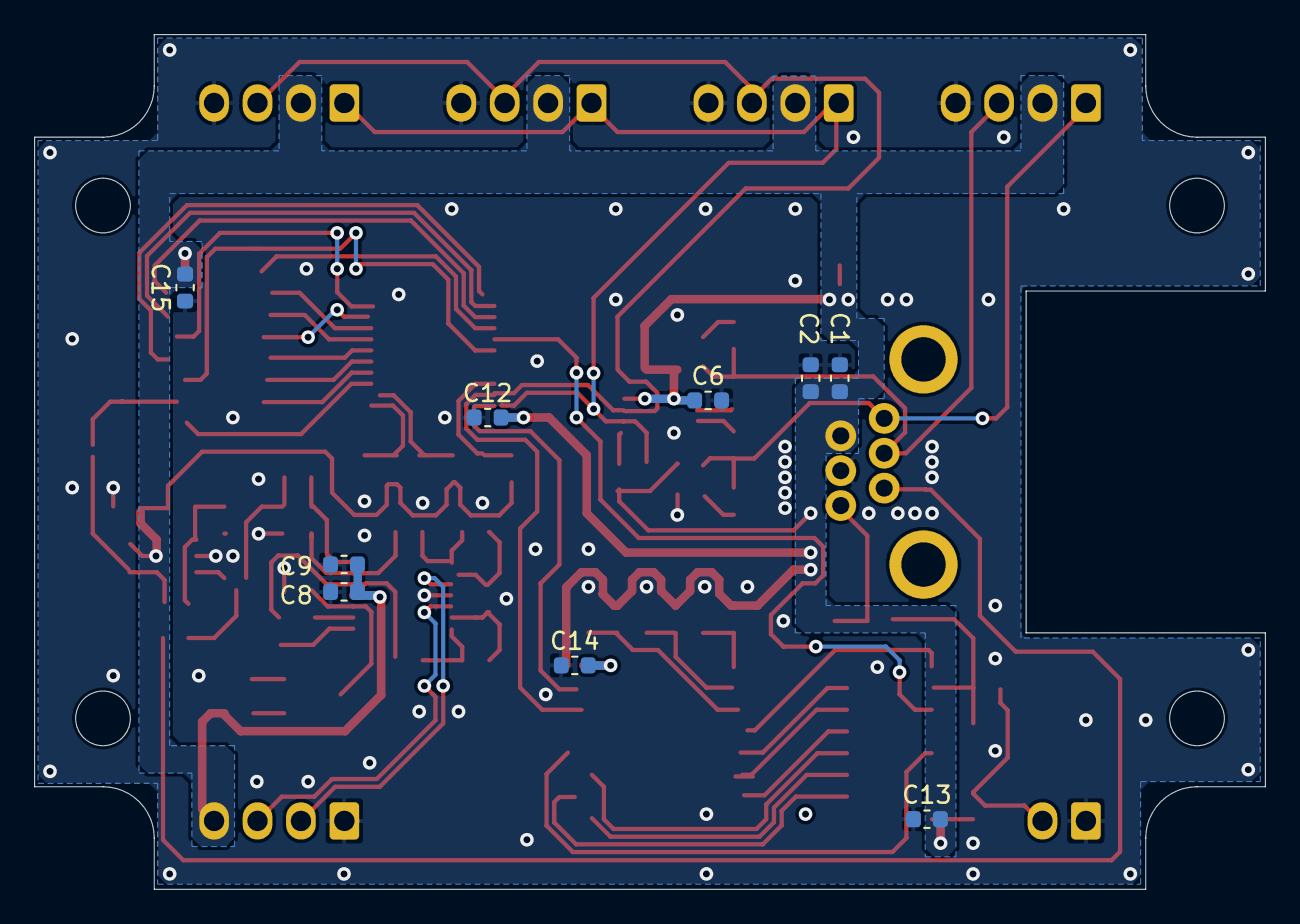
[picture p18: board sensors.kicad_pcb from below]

Board: 2 copper layers, 72.0 x 50.0 mm, 75 parts (9 on the bottom side), 60 nets.

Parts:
C1: 10uF; C_0603_1608Metric
C2, C6, C7, C10, C11, C12, C13, C14, C15: 100nF; C_0603_1608Metric
C3, C4: DNF; C_0603_1608Metric
C5: 4.7uF; C_0603_1608Metric
C8: 10nF; C_0603_1608Metric
C9: 1uF; C_0603_1608Metric
J1, J2, J4, J5, J6: Conn_01x04; Molex_KK-254_AE-6410-04A_1x04_P2.54mm_Vertical
J3: 6P6C; E5566-Q0LK22-L
J7: Conn_01x02; Molex_KK-254_AE-6410-02A_1x02_P2.54mm_Vertical
R1, R5, R7, R18, R31, R33, R35, R37, R39, R41: 0; R_0603_1608Metric
R2, R4, R6, R9, R22, R30, R32, R34, R36, R38, R40: DNF; R_0603_1608Metric
R3, R8: 2.2k; R_0603_1608Metric
R10, R11: 1k; R_0603_1608Metric
R12, R13: 75; R_0603_1608Metric
R14, R15: 33k; R_0603_1608Metric
R16, R17: 39k; R_0603_1608Metric
R19: 1.6k; R_0603_1608Metric
R20, R21, R25, R27, R29: 10k; R_0603_1608Metric
R23, R24, R28: 100k; R_0603_1608Metric
R26: 775k; R_0603_1608Metric
RV1: 10k; Potentiometer_Bourns_TC33X_Vertical
TP1, TP2, TP3, TP4: RCU-0C; TestPoint_Pad_2.0x2.0mm
U1: LMV324; TSSOP-14_4.4x5mm_P0.65mm
U2: PCA9517A; TSSOP-8_3x3mm_P0.65mm
U3: LMV331; TSOP-5_1.65x3.05mm_P0.95mm
U4, U5: MC14040B; SOIC-16_3.9x9.9mm_P1.27mm
U6: TCA9555DBR; SSOP-24_5.3x8.2mm_P0.65mm
U7: PCF8574; SOIC-16W_7.5x10.3mm_P1.27mm

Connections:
/3V3: C1.1, C2.1, C6.1, C8.2, C9.2, C10.2, C12.2, C13.2, C14.2, C15.2, J1.2, J2.2, J3.5, J4.4, J5.2, J6.2, R3.2, R8.2, R14.1, R20.2, R21.2, R23.1, R25.2, R27.1, R29.1, R30.1, R32.1, R34.1, R36.1, R38.1, R40.1, TP1.1, U1.4, U2.1, U2.8, U3.5, U4.16, U5.16, U6.24, U7.16
/ADC: J3.2, R22.1
/AN_CLR: U5.11, U6.18
/RAIN_TRG: C11.2, R2.1, R28.1, U4.10
/RG_CLR: U4.11, U6.17
/SCL: J1.3, J5.3, J6.3, R25.1, U2.7, U6.22, U7.14
/SCL_RJ11: J2.3, J3.4, R8.1, R9.1, R12.2
/SDA: J1.1, J5.1, J6.1, R21.1, U2.6, U6.23, U7.15
/SDA_RJ11: J2.1, J3.6, R3.1, R4.1, R13.2
GND: C1.2, C2.2, C3.2, C4.2, C5.1, C6.2, C7.1, C8.1, C9.1, C10.1, C11.1, C12.1, C13.1, C14.1, C15.1, J1.4, J2.4, J3.3, J4.1, J5.4, J6.4, J7.1, R1.2, R15.2, R24.2, R31.2, R33.2, R35.2, R37.2, R39.2, R41.2, TP2.1, U1.11, U2.4, U3.2, U4.8, U5.8, U6.12, U7.8
unnamed: C3.1, R4.2
unnamed: C4.1, R9.2
unnamed: C5.2, RV1.2, U1.3
unnamed: C7.2, R19.1, R22.2, TP3.1, U3.3
unnamed: J3.1, R1.1, R2.2
unnamed: J4.2, U1.10
unnamed: J4.3, U1.12
unnamed: J7.2, R27.2, R28.2
unnamed: R5.2, R6.1, U1.13
unnamed: R6.2, R7.1, U1.9
unnamed: R10.1, R17.2, U1.5
unnamed: R5.1, R10.2, U1.14
unnamed: R7.2, R11.1, U1.8
unnamed: R11.2, R16.1, U1.6
unnamed: R12.1, U2.2
unnamed: R13.1, U2.3
unnamed: R14.2, RV1.1
unnamed: R15.1, RV1.3
unnamed: R16.2, R19.2, U1.7
unnamed: R17.1, R18.2, U1.1
unnamed: R18.1, U1.2
unnamed: R20.1, U2.5
unnamed: R23.2, R24.1, R26.2, U3.1
unnamed: R26.1, R29.2, TP4.1, U3.4, U5.10
unnamed: R30.2, R31.1, U6.3
unnamed: R32.2, R33.1, U6.2
unnamed: R34.2, R35.1, U7.1
unnamed: R36.2, R37.1, U6.21
unnamed: R38.2, R39.1, U7.2
unnamed: R40.2, R41.1, U7.3
unnamed: U4.2, U7.10
unnamed: U4.3, U7.9
unnamed: U4.4, U7.11
unnamed: U4.5, U7.7
unnamed: U4.6, U7.6
unnamed: U4.7, U7.5
unnamed: U4.9, U7.4
unnamed: U4.13, U7.12
unnamed: U5.1, U6.16
unnamed: U5.2, U6.9
unnamed: U5.3, U6.8
unnamed: U5.4, U6.10
unnamed: U5.5, U6.7
unnamed: U5.6, U6.6
unnamed: U5.7, U6.5
unnamed: U5.9, U6.4
unnamed: U5.12, U6.13
unnamed: U5.13, U6.11
unnamed: U5.14, U6.14
unnamed: U5.15, U6.15

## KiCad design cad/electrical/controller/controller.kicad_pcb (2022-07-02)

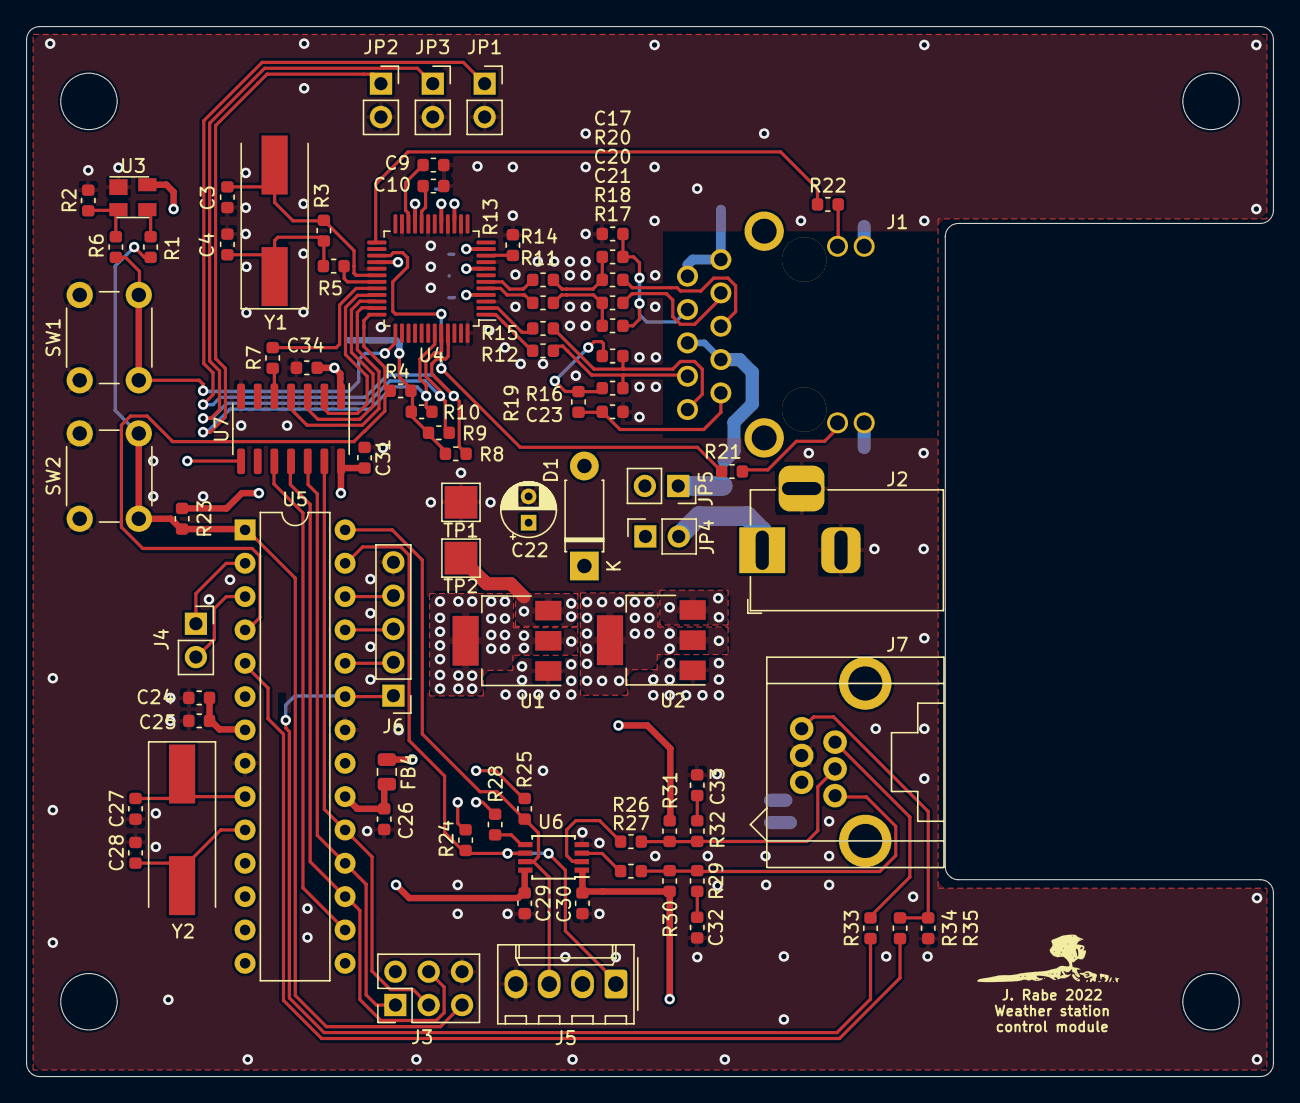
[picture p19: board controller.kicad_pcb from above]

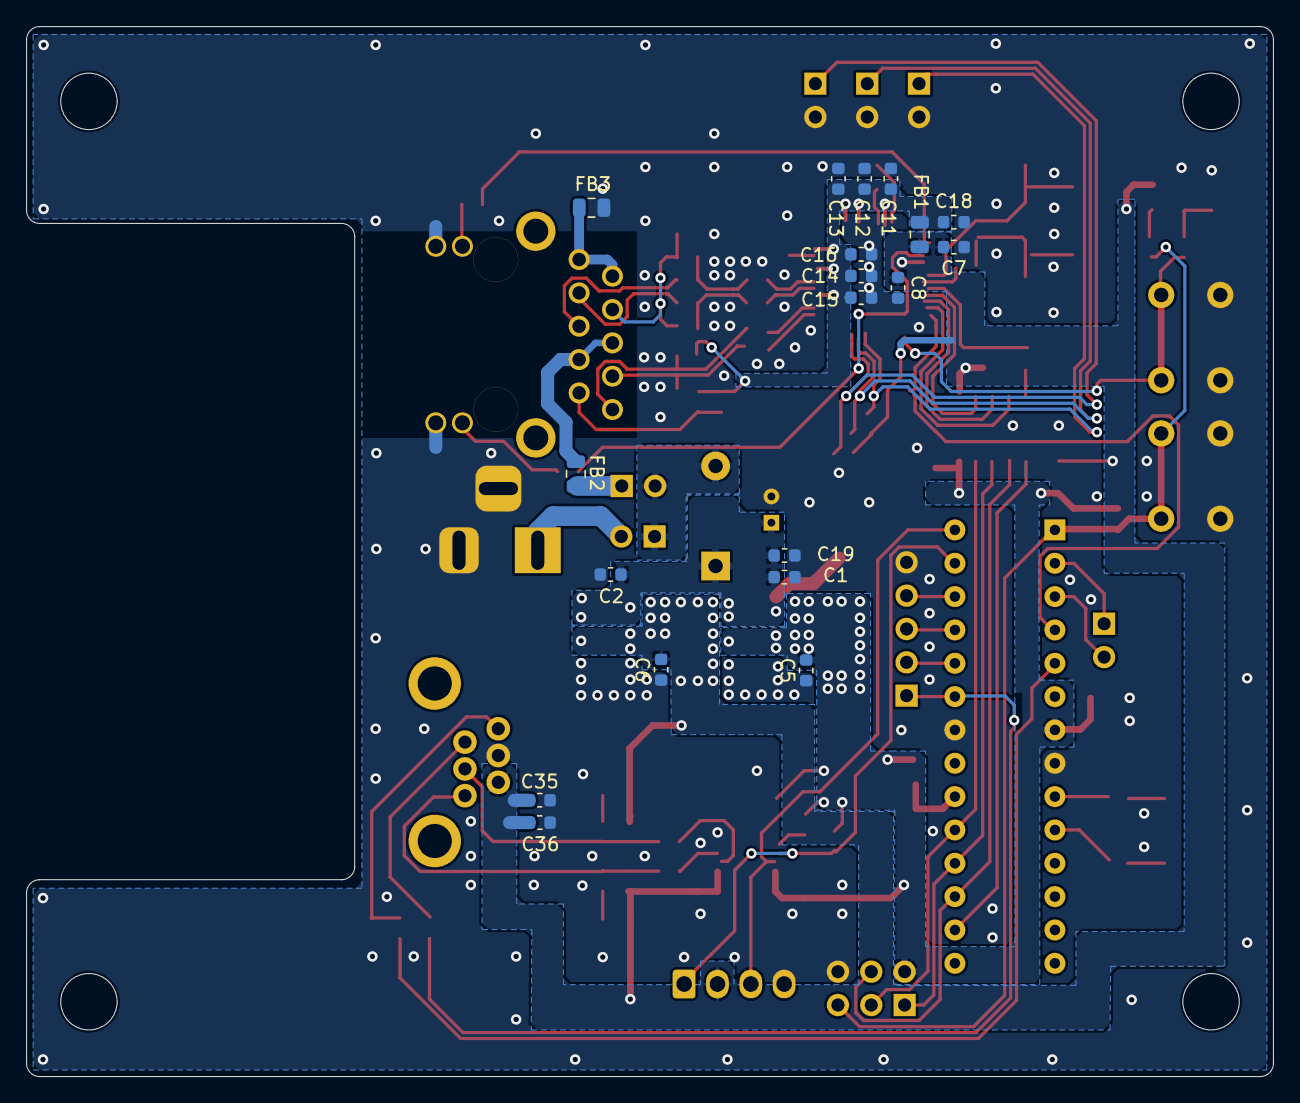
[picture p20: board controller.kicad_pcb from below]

Board: 2 copper layers, 95.0 x 80.0 mm, 101 parts (19 on the bottom side), 70 nets.

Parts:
C1, C2, C5, C6, C7, C18, C24, C35: 10uF; C_0603_1608Metric
C3, C4, C27, C28: 18pF; C_0603_1608Metric
C8, C11, C12, C13, C14, C15, C16, C19, C25, C26, C29, C30, C31, C34, C36: 100nF; C_0603_1608Metric
C9, C17: 10nF; C_0603_1608Metric
C10: 4.7uF; C_0603_1608Metric
C20, C21: 6.8nF; C_0603_1608Metric
C22: 33uF; CP_Radial_D4.0mm_P2.00mm
C23: 22nF; C_0603_1608Metric
C32, C33: DNF; C_0603_1608Metric
D1: D; D_DO-41_SOD81_P7.62mm_Horizontal
FB1, FB2, FB3, FB4: BLM21; L_0805_2012Metric
J1: RJ45_jack_POE; ARJM11C7-114-BA-EW2
J2: Barrel_Jack_Switch; BarrelJack_Horizontal
J3: Conn_02x03_Odd_Even; PinHeader_2x03_P2.54mm_Vertical
J4: Conn_01x02; PinSocket_1x02_P2.54mm_Vertical
J5: Conn_01x04; Molex_KK-254_AE-6410-04A_1x04_P2.54mm_Vertical
J6: Conn_01x05; PinHeader_1x05_P2.54mm_Vertical
J7: 6P6C; E5566-Q0LK22-L
JP1, JP2, JP3, JP4, JP5: Jumper; PinSocket_1x02_P2.54mm_Vertical
R1, R5, R7, R11, R12, R14, R15, R35: 0; R_0603_1608Metric
R2: 100k; R_0603_1608Metric
R3: 1M; R_0603_1608Metric
R4, R29, R32, R33, R34: DNF; R_0603_1608Metric
R6: 4.7k; R_0603_1608Metric
R8, R9, R10, R23, R24, R25, R28: 10k; R_0603_1608Metric
R13: 12k4; R_0603_1608Metric
R16, R17, R18, R20: 49.9; R_0603_1608Metric
R19: 10; R_0603_1608Metric
R21, R22: 330; R_0603_1608Metric
R26, R27: 75; R_0603_1608Metric
R30, R31: 2.2k; R_0603_1608Metric
SW1, SW2: SW_Push; SW_PUSH_6mm
TP1, TP2: TestPoint; TestPoint_Pad_2.5x2.5mm
U1: NCP1117-5.0_SOT223; SOT-223-3_TabPin2
U2: NCP1117-3.3_SOT223; SOT-223-3_TabPin2
U3: CAT811STBI-GT3; SOT-143
U4: W5500; LQFP-48_7x7mm_P0.5mm
U5: ATmega328-PU; DIP-28_W7.62mm
U6: PCA9517A; TSSOP-8_3x3mm_P0.65mm
U7: TXB0104D; SOIC-14_3.9x8.7mm_P1.27mm
Y1: 25MHz; Crystal_SMD_HC49-SD
Y2: 18MHz; Crystal_SMD_HC49-SD

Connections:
3V3: C6.2, C7.2, C8.2, C30.1, C34.1, C35.1, C36.1, FB1.1, J5.2, J7.5, R4.2, R8.2, R9.2, R10.2, R30.1, R31.1, U2.2, U3.4, U4.28, U6.1, U7.1, U7.8
5V0: C5.2, C24.1, C25.1, C29.1, C31.2, FB4.1, J3.2, R23.1, R24.1, R25.1, R28.1, U1.2, U5.7, U6.8, U7.14
/3V3_ANA: C11.2, C12.2, C13.2, C14.2, C15.2, C16.2, C18.2, FB1.2, R16.1, R17.1, R19.2, U4.4, U4.8, U4.11, U4.15, U4.17, U4.21
/ACT_LED: R21.2, U4.27
/LINK_LED: R22.1, U4.25
/MCU/5V0_ANA: C26.2, FB4.2, U5.20
/MCU/ADC_0: J6.1, R33.1, U5.23
/MCU/ADC_1: J6.2, U5.24
/MCU/ADC_2: J6.3, U5.25
/MCU/ADC_3: J6.4, U5.26
/MCU/CS_5V: U5.16, U7.10
/MCU/INT_SPARE: R34.1, U5.5
/MCU/MISO_5V: J3.1, U5.18, U7.12
/MCU/MOSI_5V: J3.4, U5.17, U7.11
/MCU/RX: J4.1, U5.2
/MCU/SCL: J5.3, R25.2, U5.28, U6.7
/MCU/SCLK_5V: J3.3, U5.19, U7.13
/MCU/SCL_RJ11: J7.4, R26.1, R31.2, R32.1
/MCU/SDA: J5.1, R24.2, U5.27, U6.6
/MCU/SDA_RJ11: J7.6, R27.1, R29.1, R30.2
/MCU/TX: J4.2, U5.3
/PIN_12V: C1.2, C2.2, C19.1, C22.1, D1.1, TP2.1, U1.3, U2.3
/PIN_12V_JACK: J2.1, JP4.2
/RST_W5500: R6.1, SW1.2, U4.37
CS: R7.1, U7.5
GND: C1.1, C2.1, C3.2, C4.1, C5.1, C6.1, C7.1, C8.1, C9.2, C10.2, C11.1, C12.1, C13.1, C14.1, C15.1, C16.1, C17.2, C18.1, C19.2, C22.2, C23.2, C24.2, C25.2, C26.1, C27.1, C28.2, C29.2, C30.2, C31.1, C32.2, C33.2, C34.2, C35.2, C36.2, FB3.1, J1.12, J1.14, J2.2, J2.3, J3.6, J5.4, J6.5, J7.3, JP1.2, JP2.2, JP3.2, R2.2, R13.1, R35.1, SW1.1, SW2.1, TP1.1, U1.1, U2.1, U3.1, U4.3, U4.9, U4.14, U4.16, U4.19, U4.23, U4.29, U4.48, U5.8, U5.22, U6.4, U7.7
INT_W5500: R4.1, U4.36, U5.4
MISO: U4.34, U7.3
MOSI: U4.35, U7.4
unnamed: C3.1, R3.2, U4.30, Y1.2
unnamed: C4.2, R3.1, R5.1, Y1.1
unnamed: C9.1, U4.22
unnamed: C10.1, U4.20
unnamed: C17.1, J1.4, R18.2, R20.2
unnamed: C20.1, J1.5
unnamed: C20.2, R14.2, R20.1
unnamed: C21.1, J1.3
unnamed: C21.2, R11.2, R18.1
unnamed: C23.1, J1.9, R19.1
unnamed: C27.2, U5.9, Y2.1
unnamed: C28.1, U5.10, Y2.2
unnamed: C32.1, R29.2
unnamed: C33.1, R32.2
unnamed: D1.2, JP4.1, JP5.2
unnamed: FB2.1, JP5.1
unnamed: FB2.2, J1.6, J1.7
unnamed: FB3.2, J1.1, J1.2
unnamed: J1.8, R12.2, R16.2
unnamed: J1.10, R15.2, R17.2
unnamed: J1.11, R22.2
unnamed: J1.13, R21.1
unnamed: J7.1, R34.2, R35.2
unnamed: J7.2, R33.2
unnamed: JP1.1, R8.1, U4.45
unnamed: JP2.1, R10.1, U4.43
unnamed: JP3.1, R9.1, U4.44
unnamed: R1.2, U3.3
unnamed: R2.1, R6.2, U3.2
unnamed: R5.2, U4.31
unnamed: R7.2, U4.32
unnamed: R11.1, U4.5
unnamed: R12.1, U4.1
unnamed: R13.2, U4.10
unnamed: R14.1, U4.6
unnamed: R15.1, U4.2
unnamed: R26.2, U6.2
unnamed: R27.2, U6.3
unnamed: R28.2, U6.5
RST: J3.5, R1.1, R23.2, SW2.2, U5.1
SCLK: U4.33, U7.2

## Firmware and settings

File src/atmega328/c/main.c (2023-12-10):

/*
 * main.c
 *
 * Created: 15/05/2022 7:51:12 PM
 *  Author: Jon. R
 */ 

// TODO set using compiler option
#define F_CPU 18000000UL

#include <stdio.h>
#include <stdlib.h>
#include <avr/io.h>
#include <avr/pgmspace.h>
#include <util/delay.h>
#include <stdint.h>
#include "main.h"
#include "http_server.h"
#include "sensor_api.h"
// #include "usart.h"
#include "mcp9808.h"
#include "w5500.h"

// For USART
// FILE usart0_str = FDEV_SETUP_STREAM(USART0SendByte, USART0ReceiveByte, _FDEV_SETUP_RW);


int main(void){	
	uint16_t data_size;
	char data[512];
	
	// Bring up USART for testing (need to include usart.h)
	// USART0Init();
	// stdin=stdout=&usart0_str;
	
	data_size = api_get_all(data, AVERAGES);
	
	tcp_init(mac_addr, subnet_mask, gateway, ip_addr, port);
	
	while (1){
		data_size = api_get_all(data, AVERAGES);
		tcp_open();
		tcp_listen();
		tcp_wait_established();
		
		tcp_send(data, data_size);
		
		tcp_end();
	}
	
	return 0;
}

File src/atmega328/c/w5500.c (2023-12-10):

/*
 * w5500.c
 *
 * Created: 22/05/2022 11:03:47 AM
 *  Author: Jon. R
 */ 

#include <avr/io.h>
#include <util/delay.h>
#include "spi.h"
#include "w5500.h"
// #include "usart.h"

// SPI control
uint8_t _get_socket_BSB(uint8_t socket, uint8_t mode){
	return ((socket*4) + mode) << BSB_BIT_OFFSET;
}


uint8_t _w5500_spi_n(uint8_t write, uint8_t bsb, uint16_t addr, uint8_t* data, int len){
	uint8_t addr1 = (uint8_t)(addr >> 8);
	uint8_t addr2 = (uint8_t)(addr & 0xff);
	uint8_t error = 0;
	
	spi_set_chip_select(0);
	spi_write(addr1);
	error |= spi_collision();
	spi_write(addr2);
	error |= spi_collision();
	spi_write(write | bsb);
	error |= spi_collision();
	
	for (int i=0; i<len; i++) {
		if (write) {
			spi_write(data[i]);
		}
		else {
			data[i] = spi_read();
		}
		error |= spi_collision();
	}
	spi_set_chip_select(1);
	
	return error;
}


uint8_t w5500_write_n(uint8_t socket, uint8_t mode, uint16_t addr, uint8_t* data_tx, int len){
	return _w5500_spi_n(W5500_WRITE, _get_socket_BSB(socket, mode), addr, data_tx, len);
}


uint8_t w5500_read_n(uint8_t socket, uint8_t mode, uint16_t addr, uint8_t* data_rx, int len){
	return _w5500_spi_n(W5500_READ, _get_socket_BSB(socket, mode), addr, data_rx, len);
}


uint8_t w5500_write_byte(uint8_t socket, uint8_t mode, uint16_t addr, uint8_t byte){
	uint8_t* _byte = &byte;
	return w5500_write_n(socket, mode, addr, _byte, 1);
}


uint8_t w5500_init(void){
	spi_init();
	return w5500_write_byte(0, COMMON, MODE, 0x80);
}


uint8_t w5500_get_status(int socket){
	uint8_t status;
	w5500_read_n(socket, SOCK_n, S0_SR, &status, 1);
	
	return status;
}


void w5500_set_command(int socket, uint8_t cmd){
	uint8_t _cmd = cmd;
	w5500_write_byte(socket, SOCK_n, S0_CR, cmd);
	
	while (_cmd != 0) {
		w5500_read_n(socket, SOCK_n, S0_CR, &_cmd, 1);
	}
}


void w5500_tcp_init(int socket, uint16_t source_port){
	uint8_t _source_port[] = {
		(uint8_t)(source_port >> 8), 
		(uint8_t)(source_port & 0xff)
	};
	
	// Enable TCP and write source port
	w5500_write_byte(socket, SOCK_n, S0_MR, 0x01);
	w5500_write_n(socket, SOCK_n, S0_PORT0, _source_port, 2);
}


void w5500_rx_set_size(int socket, uint8_t size){
	w5500_write_byte(socket, SOCK_n, S0_RXBUF_SIZE, size);
}


uint16_t w5500_rx_rsr(int socket){
	uint8_t size[2];
	w5500_read_n(socket, SOCK_n, S0_RX_RSR0, size, 2);
	
	return (((uint16_t) size[0]) << 8) | ((uint16_t) size[1]);
}


uint16_t w5500_rx_size(int socket){
	uint8_t reg;
	w5500_read_n(socket, SOCK_n, S0_RXBUF_SIZE, &reg, 1);
	
	return ((uint16_t) reg) * 0x400;
}


void w5500_tx_set_size(int socket, uint8_t size){
	w5500_write_byte(socket, SOCK_n, S0_TXBUF_SIZE, size);
}


uint16_t w5500_tx_fsr(int socket){
	uint8_t size[2];
	w5500_read_n(socket, SOCK_n, S0_TX_FSR0, size, 2);
	
	return (((uint16_t) size[0]) << 8) | ((uint16_t) size[1]);
}


uint16_t w5500_tx_size(int socket){
	uint8_t reg;
	w5500_read_n(socket, SOCK_n, S0_TXBUF_SIZE, &reg, 1);
	
	return ((uint16_t) reg) * 0x400;
}


uint16_t w5500_tcp_rx(int socket, uint8_t* buffer, uint16_t buffer_size) {
	uint8_t _rx_pt[2];
	uint16_t rx_pt = 0;
	uint16_t rx_size = w5500_rx_rsr(socket);
	uint16_t read_size;
	uint16_t buffer_pt = 0;
	uint16_t buffer_remain = buffer_size;
	
	while((rx_size > 0) && buffer_remain) {
		w5500_read_n(socket, SOCK_n, S0_RX_RD0, _rx_pt, 2);
		rx_pt = ((uint16_t)_rx_pt[0] << 8) | ((uint16_t)_rx_pt[1]);
		read_size = rx_size>buffer_remain ? buffer_remain : rx_size;
		
		w5500_read_n(socket, SOCK_n_RX_BUF, rx_pt, buffer+buffer_pt, read_size);
		buffer_pt += read_size;
		rx_pt += read_size;
		buffer_remain -= read_size;
		
		w5500_write_byte(socket, SOCK_n, S0_RX_RD0, (rx_pt >> 8));
		w5500_write_byte(socket, SOCK_n, S0_RX_RD1, (rx_pt & 0xff));
		w5500_set_command(socket, RECV);
		
		rx_size = w5500_rx_rsr(socket);
		}
		
	return buffer_pt;
}


void w5500_tcp_tx(int socket, uint8_t* data, uint16_t data_size){
	uint16_t free_size = w5500_tx_fsr(socket);
	uint8_t _write_pt[2];
	uint16_t write_pt = 0;
	uint8_t offset = 0;
	
	do {
		w5500_read_n(socket, SOCK_n, S0_TX_WR0, _write_pt, 2);
		write_pt = ((uint16_t)_write_pt[0] << 8) | ((uint16_t)_write_pt[1]);
	
		w5500_write_n(socket, SOCK_n_TX_BUF, write_pt, data+offset,
						data_size>free_size? free_size : data_size);
	
		offset += free_size;
		write_pt += data_size;
		data_size -= free_size;
		
		uint8_t size_upper = (uint8_t) (write_pt >> 8);
		uint8_t size_lower = (uint8_t) (write_pt & 0xff);
		w5500_write_byte(socket, SOCK_n, S0_TX_WR0, size_upper);
		w5500_write_byte(socket, SOCK_n, S0_TX_WR1, size_lower);
	
		free_size = w5500_tx_fsr(socket);
		w5500_set_command(socket, SEND);
	} while(free_size == 0);
}


uint8_t w5500_assign_network_addr(uint16_t addr_reg, uint8_t* addr, uint8_t length){	
	return w5500_write_n(0, COMMON, addr_reg, addr, length);
}

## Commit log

2022-03-02 Initial commit. Added CAD files, libraries and project notebook
    [controller.kicad_pcb, controller.sch]
2022-03-06 Chose ethernet jack and completed schematic capture for W5500.
    [controller.sch]
2022-03-14 Finished majority of schematic capture. Need to add sensors and sensor headers
    [controller.sch]
2022-03-21 Added cad project for wind sensors board. Added AMR sensor conditioning circuitry to sensor breakout board
    [MCU.sch, sensors.kicad_pcb, sensors.sch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]
2022-03-26 Added decoupling inductors and capacitors
    [MCU.sch, controller.sch, sensors.sch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]
2022-03-31 Ordered components
    [MCU.sch, controller.sch, sensors.sch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]
2022-04-02 Changed I2C buffer to PCA1517, added termination network on RJ11 I2C lines
    [MCU.sch, controller.sch, sensors.sch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]
2022-04-18 Final commit before moving to project repo
    [sensors.sch]
2022-04-19 Added custom libraries submodule and updated the symbol tables in the kicad projects
    [MCU.sch, controller.sch, sensors.sch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]
2022-04-27 Started associating footprints with controller schematic
    [MCU.sch, controller.sch]
2022-04-30 Ready to begin layout
    [MCU.sch, controller.sch]
2022-05-01 controller placement in progress
    [MCU.sch, controller.kicad_pcb, controller.sch]
2022-05-04 controller layout
    [controller.kicad_pcb]
2022-05-07 Continued controller board placement
    [MCU.sch, controller.kicad_pcb, controller.sch]
2022-06-02 Finished placement of controller
    [MCU.sch, controller.kicad_pcb, controller.sch]
2022-06-05 Began routing controller
    [MCU.sch, controller.kicad_pcb, controller.sch]
2022-06-06 Continued controller routing
    [MCU.sch, controller.kicad_pcb, controller.sch]
2022-06-07 Continued routing controller board
    [MCU.sch, controller.kicad_pcb, controller.sch]
2022-06-08 Continued routing controller
    [controller.kicad_pcb]
2022-06-15 Finished layout of controller (need to fix silkscreen and generate gerbers)
    [controller.kicad_pcb, controller.sch]
2022-06-15 Defined sensor board outline. Began assigning footprints
    [sensors.kicad_pcb, sensors.sch]
2022-06-18 Finished sensor breakout board placement. Ready to begin routing
    [sensors.kicad_pcb, sensors.sch]
2022-06-19 Finished routing sensor breakout board. Need to draw power planes
    [sensors.kicad_pcb, sensors.sch]
2022-06-22 Begain routing planes on sensor board
    [sensors.kicad_pcb]
2022-06-23 routing power planes on sensor board
    [sensors.kicad_pcb]
2022-06-24 Finished sensor board layout
    [sensors.kicad_pcb]
2022-06-24 Finished routing wind sensor(s) board
    [controller.kicad_pcb, sensors.kicad_pcb, wind_sensors.kicad_pcb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]
2022-07-02 Finished PCB layout
    [MCU.sch, controller.kicad_pcb, sensors.kicad_pcb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]
2022-07-18 Added data
    [NewFile3.csv, NewFile4.csv]
2022-07-21 Adde controller board debug data
    [NewFile3.csv, NewFile4.csv, spi.csv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]
2022-07-23 added debug dir
    [MCU.sch, NewFile3.csv, NewFile4.csv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]
2022-07-25 updated src
    [spi.csv]
2022-08-01 Added MCP9808 temperature sensor driver
2022-08-11 w5500 and bme280 drivers working
2022-08-13 Finished w5500 driver bring-up, sensor api and http server
2023-03-19 Finished docker configuration. Added averaging to sensor measurements on MCU side. The project is stable and deployed
2023-05-23 Added new system diagram
    [MCU.sch, controller.kicad_pcb, controller.sch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]
2023-06-03 added cad
    [MCU.sch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]
2023-08-06 added I2C status code checks
2023-09-10 i2c validation refactor complete
